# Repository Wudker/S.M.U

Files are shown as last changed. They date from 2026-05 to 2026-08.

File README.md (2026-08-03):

# S.M.U. – Custom RLC Component Meter

S.M.U. is a portable RLC meter based on the Raspberry Pi Pico, developed for testing coils and passive components during electronics prototyping. Resistance is measured using a voltage divider, capacitance through RC discharge timing to approximately 37% of the initial voltage, and inductance through LC resonance and frequency analysis. Custom measurement algorithms and automatic range switching process the signals, while an SSD1306 OLED presents the results. The device combines analog measurement circuits, embedded software, a custom PCB and Li-Ion power supply in a single enclosure.

## Technologies

`Raspberry Pi Pico` `C/C++` `ADC measurements` `RC time constant` `LC resonance` `LM339 comparator` `SSD1306 OLED` `Custom PCB` `Li-Ion battery`

## Usage and development status

Select resistance, capacitance or inductance mode, place the unpowered component in the measurement connector and start the measurement. Capacitors should always be fully discharged before being connected. The prototype has been built and tested; future improvements include increased accuracy, more reliable auto-ranging, improved stability and a redesigned analog front-end.

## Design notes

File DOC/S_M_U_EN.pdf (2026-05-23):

# S.M.U. Project

Final prototype documentation

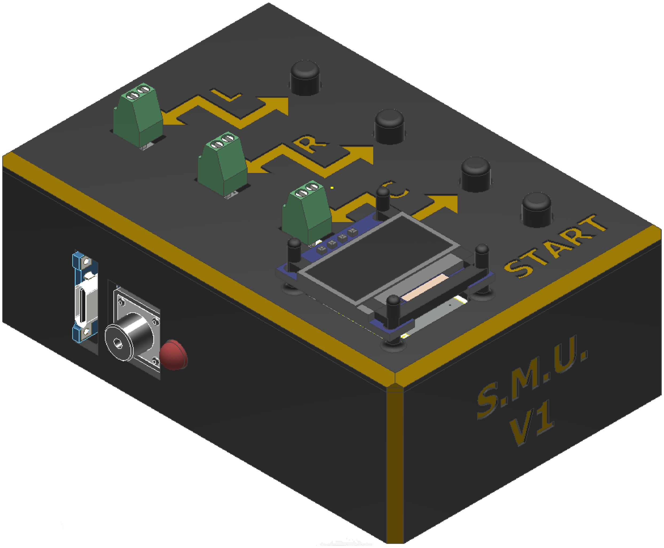
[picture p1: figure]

Author | Eng. Bartłomiej Dusza
Revision | Rev. A
Date | January 25, 2026
Version | 1.0

This document summarizes the prototype stage of the S.M.U. device and describes its design assumptions, construction and operation.

# Contents

1 Concept | 2
2 Application | 8
3 Direction of further development | 13

# Concept

## 1.1 Device idea and purpose

The aim of the project was to create a meter capable of measuring typical electronic components used in mechatronics. The version described in this document is a first prototype, built to check whether the selected measurement methods work in practice and to assess the possibility of developing a complete device. This part of the project focused mainly on the measurement section, while a ready-made microcontroller board was used for calculations and result interpretation. The Raspberry Pi Pico was selected for this project because it was inexpensive and allowed testing a different family of microcontrollers.

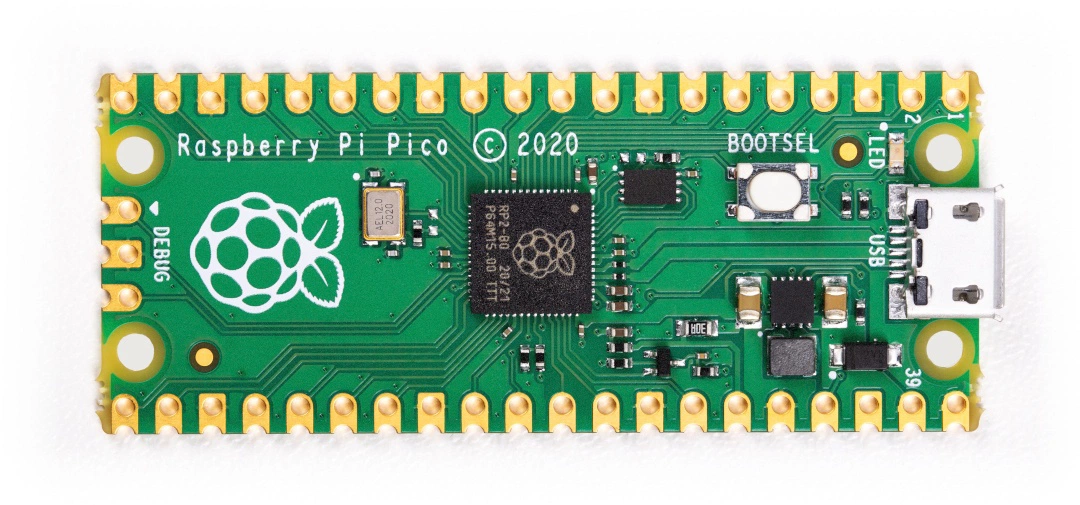
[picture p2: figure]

Figure 1.1: Selected microcontroller module.

## 1.2 Resistance measurement

Resistance measurement is based on a voltage divider and a reference resistor. The value of the measured resistor is calculated from the voltage measured by the microcontroller ADC.

The reference resistor values were selected to keep the ADC reading in a useful part of its input range for different measured resistances.

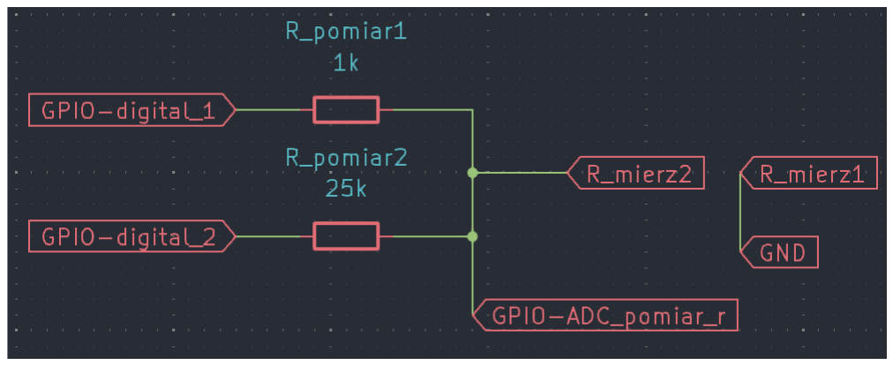
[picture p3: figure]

Figure 1.2: Resistance measurement circuit diagram.

## 1.3 Capacitance measurement

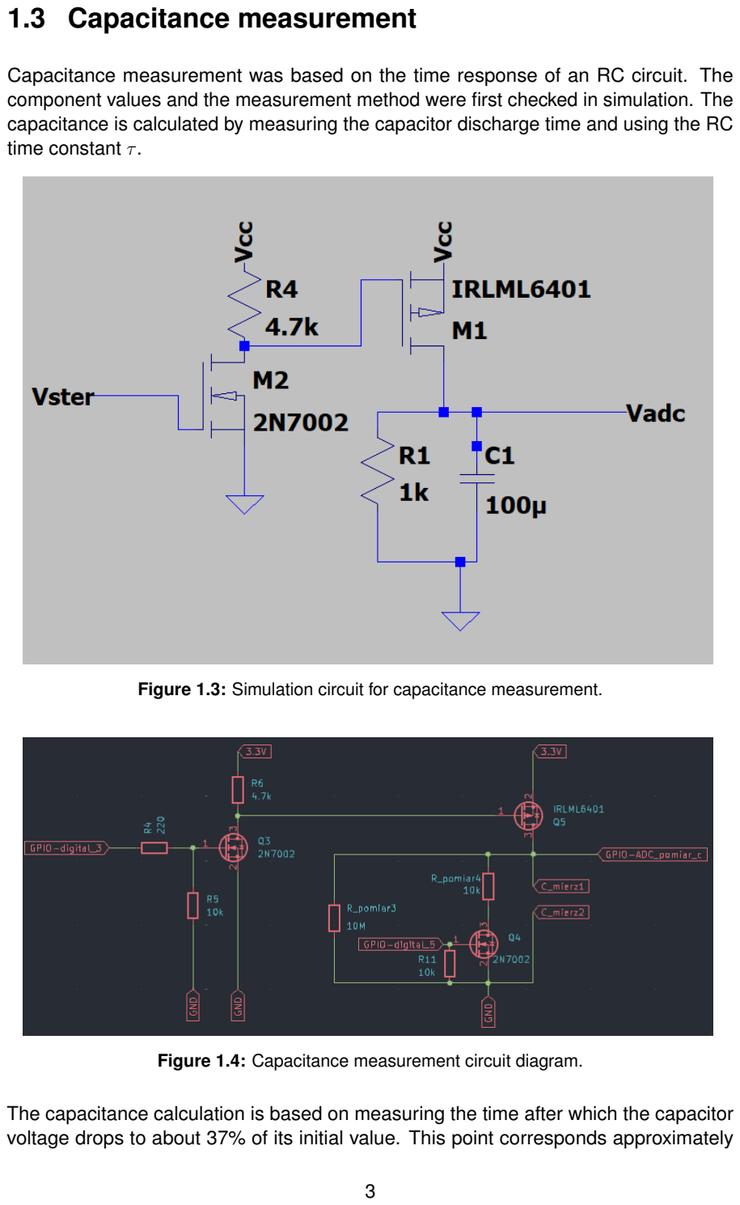
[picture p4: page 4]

Capacitance measurement was based on the time response of an RC circuit. The component values and the measurement method were first checked in simulation. The capacitance is calculated by measuring the capacitor discharge time and using the RC time constant τ .

Figure 1.3: Simulation circuit for capacitance measurement.

Figure 1.4: Capacitance measurement circuit diagram.

The capacitance calculation is based on measuring the time after which the capacitor voltage drops to about 37% of its initial value. This point corresponds approximately

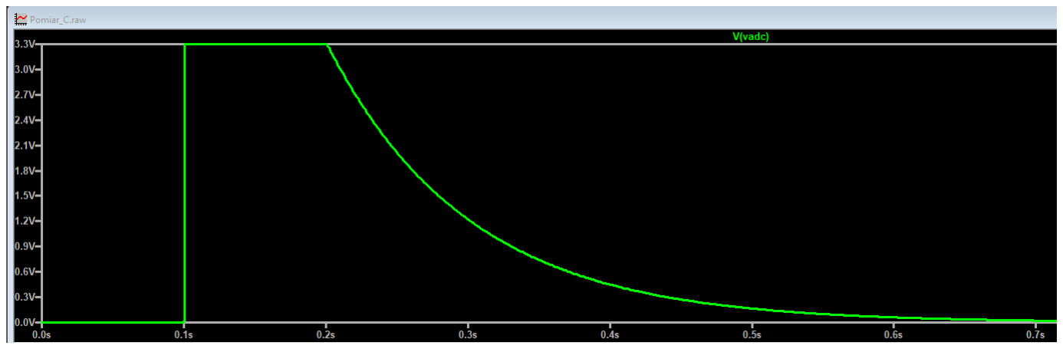
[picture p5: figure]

Figure 1.5: Simulation result of the measurement circuit.

to one time constant. Two measurement resistors were used to cover a wider range of capacitances. For large capacitances and a high resistance value, the measurement time could become too long. For small capacitances and a low resistance value, the discharge could be too fast for reliable measurement by the microcontroller. For this reason, an additional parallel resistor was added and switched by an N-MOSFET. This reduced the measurement resistance from 1 MΩ to about 10 kΩ when needed.

## 1.4 Inductance measurement

Inductance measurement was based on the resonant frequency of an LC circuit. Before building the practical circuit, simulations were performed to check the adopted measurement idea. The measured inductance is calculated from the resonant frequency of the LC circuit, using a known capacitance value.

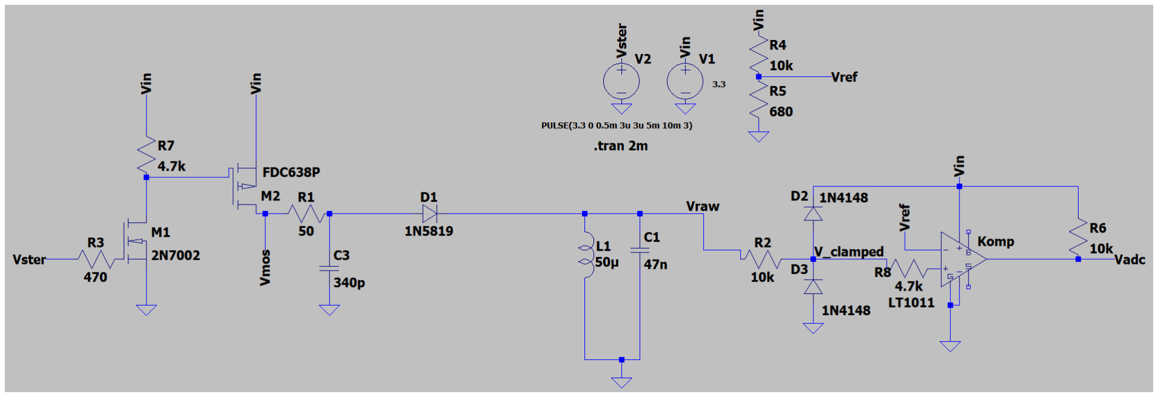
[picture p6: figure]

Figure 1.6: Simulation circuit for inductance measurement.

In the first version of the prototype, an amplifier was used between the resonant circuit and the comparator. After testing, it was removed because the circuit could work without it. The amplifier was originally intended to increase the amplitude of the signal from the resonant circuit. Schottky diodes were used as clamps to limit the negative part of the signal and allow the comparator to work correctly. The comparator converts the analog oscillating signal into a digital signal that is easier for the microcontroller to count.

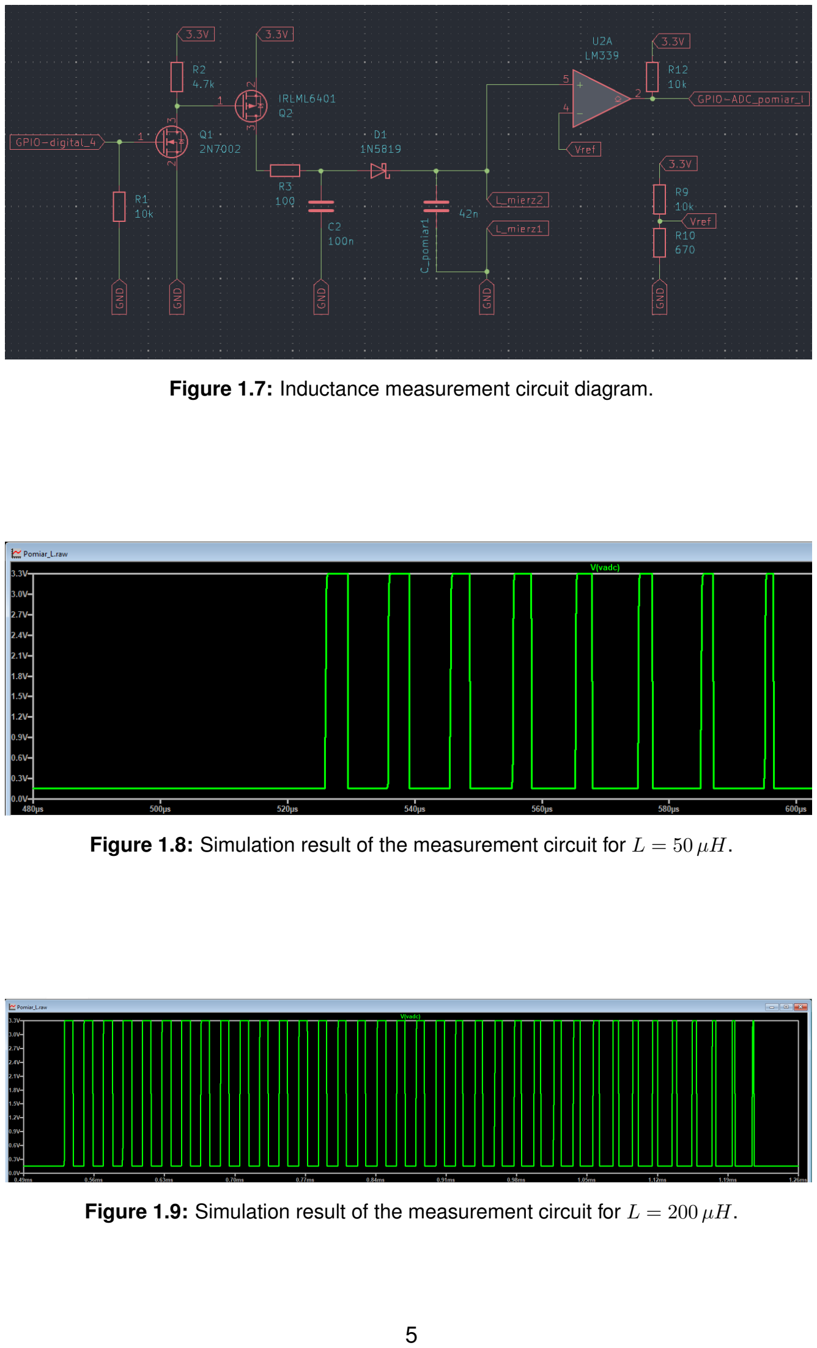
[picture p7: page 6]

Figure 1.7: Inductance measurement circuit diagram.

Figure 1.8: Simulation result of the measurement circuit for L = 50 µH.

Figure 1.9: Simulation result of the measurement circuit for L = 200 µH.

## 1.5 Power supply section

The project included USB power supply and the possibility of charging a battery cell. The power supply section was designed to make the device easy to use and allow further development.

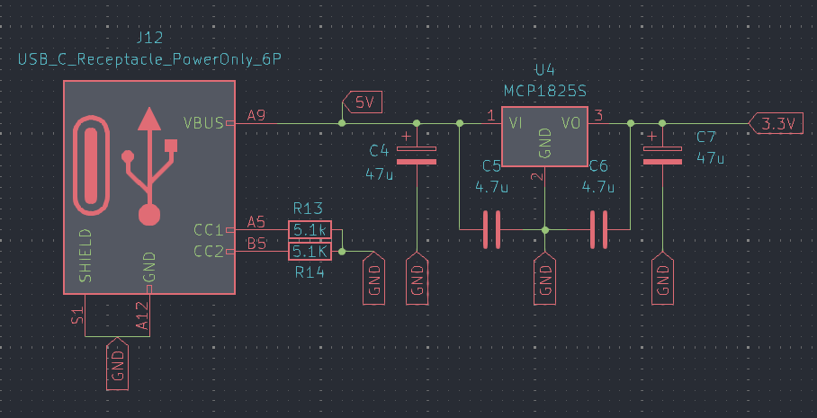
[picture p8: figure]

Figure 1.10: USB power supply handling circuit diagram.

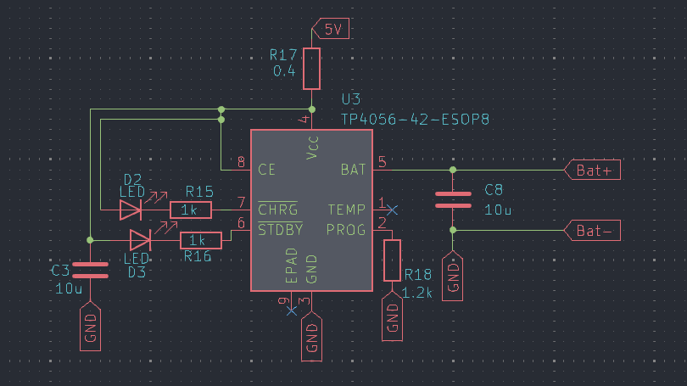
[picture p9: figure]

Figure 1.11: Battery cell charging circuit diagram.

Later, it was noticed that the TP4056 chip requires the “TEMP” pin to be connected to GND when this function is not used. More importantly, the chip is responsible only for the charging process and does not provide full battery protection. In this configuration, the circuit was not fully safe, because there was no protection system monitoring the battery cell. Such protection circuits usually use a pair of back-to-back N-MOSFETs to disconnect the cell from the system when an unsafe condition is detected. After analyzing this problem, the USB and TP4056 section was not assembled. Instead, a ready-made charging module with battery protection was used.

## 1.6 PCB

Based on the prepared schematic, a printed circuit board was designed. The top and bottom sides of the PCB are shown below.

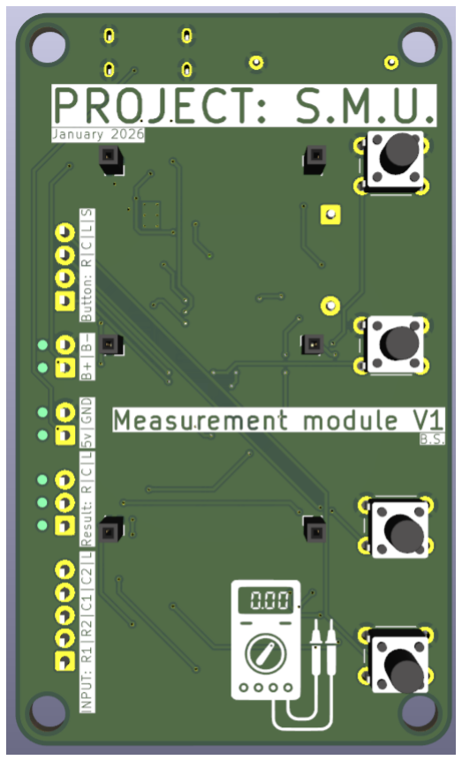
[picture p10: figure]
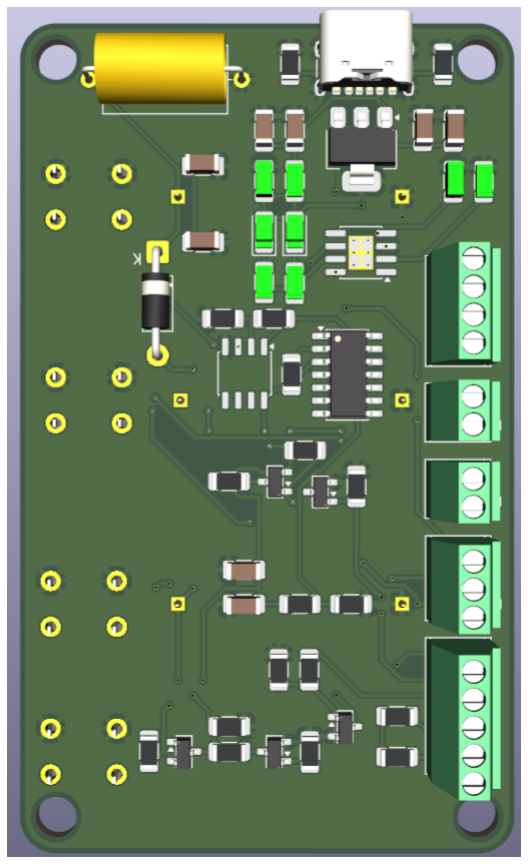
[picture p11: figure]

(a) PCB front side. | (b) PCB back side.

Figure 1.12: View of the designed PCB.

Compared with the original PCB design, the final assembled version does not include the TP4056 circuit or the amplifier, for the reasons described earlier. In addition, clamp diodes were added to ensure proper operation of the comparator. Another change was related to the measuring capacitor in the resonant path used for inductance measurement. A precision film capacitor with a different pin layout than the one used in the original design was installed.

# Application

## 2.1 Accuracy

To evaluate the operation of the device, a series of five measurements was performed for selected components. For resistance and capacitance, the results were compared with the average value obtained from a reference meter. For inductance, due to the lack of reference meter data, the results were compared with the nominal values of the tested coils.

### 2.1.1 Resistance

Results table

Table 2.1: Comparison of resistance measurement results

Element | Average value from reference meter | Average value from S.M.U. | Error relative to refer-ence
100 Ω | 97.64 Ω | 96.50 Ω | -1.17%
1 kΩ | 972.24 Ω | 956.23 Ω | -1.65%
47 kΩ | 46.962 kΩ | 44.032 kΩ | -6.24%
100 kΩ | 96.372 kΩ | 87.646 kΩ | -9.05%
1 MΩ | 1.0036 MΩ | 0.5204 MΩ | -48.15%

Description

Based on the measurements, the circuit correctly measures resistance in the lower and middle part of the tested range. For the 100 Ω and 1 kΩ resistors, the deviation from the reference value did not exceed 2%. As the measured resistance increased, the error also increased, which was visible for 47 kΩ and 100 kΩ. The largest deviation occurred for the 1 MΩ resistor, where the measured value was almost two times lower than the reference value.

Conclusions

The resistance measurement circuit can be considered suitable for low and medium resistance values. In the current prototype version, the biggest problems appear at high resistances, where ADC resolution, reference resistor tolerance and noise have a much stronger influence on the result. This section requires further improvement if the device is to measure values in the range of hundreds of kiloohms and megaohms reliably.

Theoretical and practical range

The theoretical resistance measurement range results directly from the voltage divider relation:

UADC = VCC

Rx
Rx + Rw
where Rx is the measured resistance and Rw is the reference resistor. In practice, the most useful ADC operating area is not at the very beginning or end of the scale, but rather in the middle part of the characteristic. With a simple assumption that, for more accurate calculation, it is convenient to keep the ADC input voltage in the range of about 10%–90% of full scale, the following relation is obtained:

0.1 ≤

Rx
Rx + Rw

≤ 0.9

which after transformation gives approximately:

0.11 Rw ≤ Rx ≤ 9 Rw

For an example reference resistor Rw = 10 kΩ, this gives a range of about:

1.1 kΩ ≤ Rx ≤ 90 kΩ

which is approximately from about 1 kΩ to 100 kΩ for more accurate calculation. With a wider but less favorable use of the ADC range, for example about 5%–95%, the approximate range would be from about 0.5 kΩ to about 190 kΩ. The actual results showed that in the current prototype version the useful range mainly covered values from about 100 Ω to about 100 kΩ, while for 1 MΩ the error was already too large to consider this point reliable.

### 2.1.2 Capacitance

Results table

Table 2.2: Comparison of capacitance measurement results

Element | Average value from reference meter | Average value from S.M.U. | Error relative to refer-ence
1000 µF | 1072.6 µF | 1036.0 µF | -3.41%
470 µF | 481.38 µF | 439.93 µF | -8.61%
100 µF | 124.24 µF | 102.14 µF | -17.79%
10 µF | 11.56 µF | 9.316 µF | -19.41%
100 nF | 146.03 nF | 32.08 nF | -78.03%

Description

For capacitance measurement, correct and repeatable results were obtained for larger capacitances, especially in the range of 470 µF–1000 µF. As the capacitance decreased, the measurement error increased. For 100 µF and 10 µF capacitors, the result was clearly lower than the reference value. For 100 nF, the measurement was incorrect. This shows that the method works well for larger time constants, but for small capacitances parasitic effects and timing limitations become dominant.

Conclusions

The capacitance measurement section works correctly for capacitors with larger values, while the lower range requires further optimization. The results suggest that in the current configuration the circuit is more useful for measuring electrolytic capacitors and larger capacitors than for precise measurement of small capacitances. In particular, for the nanofarad range, changing the measurement components or using another method should be considered.

Theoretical and practical range

For capacitance measurement, the starting point was the time constant relation:

τ = R C

where the measurement was based on determining the time required for the voltage to drop to about 37% of the initial value, which corresponds to one time constant τ . Two measuring resistors were used in the project: about 1 MΩ and about 10 kΩ, with the second value obtained by connecting a parallel branch. Therefore, the theoretical range can be estimated by assuming that a convenient measurement time for the microcontroller is roughly between 10 ms and 10 s.

For R = 1 MΩ:
C =

τ
R

Cmin ≈

10 ms
1 MΩ

= 10 nF

Cmax ≈

10 s
1 MΩ

= 10 µF

For R = 10 kΩ:

Cmin ≈

10 ms
10 kΩ

= 1 µF

Cmax ≈

10 s
10 kΩ

= 1000 µF

This gives a total theoretical range of about 10 nF to about 1000 µF, where the lower part of the range is mainly covered by the 1 MΩ resistor and the upper part by the resistor of about 10 kΩ. In practice, the obtained results showed that the current prototype version worked correctly mainly from about 10 µF to about 1000 µF. Although simple calculations suggest that lower values should also be possible, for small capacitances parasitic capacitances, component tolerances and timing limitations of the circuit became increasingly important. As a result, for 100 nF the error was already very large.

### 2.1.3 Inductance

Results table

Table 2.3: Comparison of inductance measurement results

Element | Nominal value | Average value from S.M.U. | Error relative to nomi-nal value
330 µH | 330 µH | 329.87 µH | -0.04%
220 µH | 220 µH | 170.09 µH | -22.69%
100 µH | 100 µH | 106.27 µH | +6.27%

Description

For inductance measurement, the results were mixed. For the 330 µH coil, the measured value was very close to the nominal value, which supports the measurement idea based on the resonant method. For 100 µH, the deviation was still acceptable. The biggest problem appeared for 220 µH, where the result was significantly lower than the nominal value. This may be caused by parasitic parameters of the tested coil, limited frequency counting stability or a faulty coil sample.

Conclusions

Inductance measurement can be considered promising, but in the current version it is not yet fully stable across the entire tested range. The very good result obtained for 330 µH shows that the circuit has potential, but the error spread for the other coils suggests the need for further calibration and better consideration of parasitic elements. In practice, this means that this section still requires improvement before it can be considered fully universal.

Theoretical and practical range

For inductance measurement, the relation for the resonant frequency of an LC circuit was used:
f =

1
2π

√
LC
after transformation:
L =

1
(2πf)
2C

Assuming a reference capacitor Cref = 42 nF, it is possible to estimate what inductance range corresponds to frequencies convenient for further counting and processing by the circuit. For an approximate frequency range from about 40 kHz to 110 kHz, the following values are obtained:

for f = 110 kHz:

L ≈

1
(2π · 110000)²
- 42 · 10⁻⁹

≈ 50 µH

for f = 40 kHz:

L ≈

1
(2π · 40000)²
- 42 · 10⁻⁹

≈ 377 µH

This gives a theoretical operating range of about:

50 µH ≤ L ≤ 380 µH

It is worth noting that for values close to the tested ones, frequencies consistent with the idea of this method are obtained: for 100 µH about 78 kHz, for 200 µH about 55 kHz, and for 330 µH about 43 kHz. This means that the adopted range from several dozen to several hundred µH was theoretically justified. In practice, values from 100 µH to 330 µH were tested, and the best agreement was obtained for 330 µH, while for 220 µH a clear error appeared. This shows that the method itself was correct, but the practical range of accurate measurement turned out to be narrower than the range resulting from a simple theoretical model.

Summary of the measurement section

The measurements confirmed that the adopted measurement methods can work in practice, but they also showed that the device accuracy strongly depends on the tested value range. The best results were obtained in the middle parts of the measurement ranges, where the values were close to the reference values and showed good repeatability. The largest deviations appeared at extreme values. This indicates the influence of method limitations, parasitic component parameters and the resolution of the measurement path. The prototype fulfilled its verification role and helped identify the areas that require further improvement.

# Direction of further development

After analyzing the results, it can be concluded that the measurement circuit concept is valid. However, the results also show that in the next version it is necessary to:

- carefully analyze the measurement ranges and add more measurement elements,
- remove the ready-made charging module,
- add protection circuits for the battery cell,
- replace the ready-made microcontroller module with a dedicated microcontroller circuit,
- analyze available microcontrollers and choose one with a suitable ADC, or use an external ADC,
- consider a better physical connector for the measured components,
- add protection against reverse connection of electrolytic capacitors.

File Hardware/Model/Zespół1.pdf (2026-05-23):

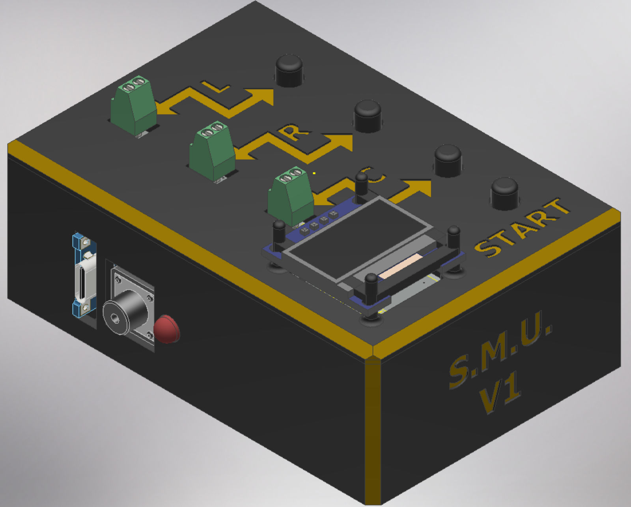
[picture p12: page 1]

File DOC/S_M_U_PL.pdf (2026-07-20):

Projekt S.M.U.

Dokumentacja koncowa prototypu ´


Autor | Inz. Bartłomiej Dusza ˙
Rewizja | Rev. A
Data | 25 stycznia 2026
Wersja | 1.0

Niniejszy dokument stanowi podsumowanie etapu projektu urz ˛adzenia oraz opis jego załoze˙ n,´ budowy i działania.

# Spis tresci ´

1 Pomysł | 2
1.3 Pomiar pojemnosci | ´ | 3
2 Zastosowanie | 8
2.1 Dokładnos´c | ´ | 8
2.1.2 Pojemnos´c | ´ | 9
3 Kierunek rozwoju | 13

# Pomysł

## 1.1 Idea i cel urz ˛adzenia

Celem projektu było stworzenie miernika umozliwiaj ˛acego pomiar warto ˙ | sci typowych ´
elementów elektronicznych wykorzystywanych w zakresie mechatroniki. Opisana w tym dokumencie wersja stanowi pierwszy krok maj ˛acy na celu sprawdzenie poprawnosci ´
idei pomiarów oraz ocen˛e mozliwo ˙ | sci wykonania kompletnego układu. Cz˛e ´ | s´c projektu ´
skupiała si˛e głównie na sekcji pomiarowej, a do obliczen i interpretacji wyników wyko- ´ rzystano gotow ˛a płytk˛e z mikrokontrolerem. Dla tego projektu wybrano Raspberry Pi Pico; decyzj˛e t˛e podj˛eto ze wzgl˛edu na ch˛ec sprawdzenia pracy z t ˛a rodzin ˛a układów ´ oraz korzystn ˛a cen˛e.

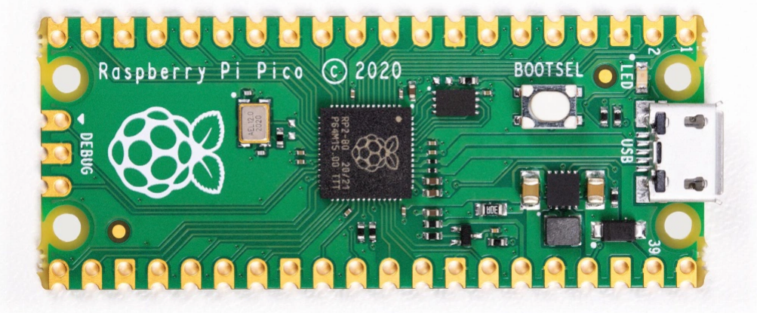
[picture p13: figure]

Rysunek 1.1: Wybrany moduł mikrokontrolera.

## 1.2 Pomiar rezystancji

Zamysł pomiaru rezystancji opiera si˛e na wykorzystaniu dzielnika napi˛ecia oraz dokładnego rezystora wzorcowego. Wartos´c mierzonego rezystora obliczana jest na podstawie ´ spadków napi˛ecia w obwodzie.

W celu dobrania wartosci rezystorów wzorcowych kierowano si˛e bilansem pomi˛edzy ´ skrajnym zakresem wartosci odczytywanych przez przetwornik ADC mikrokontrolera. ´

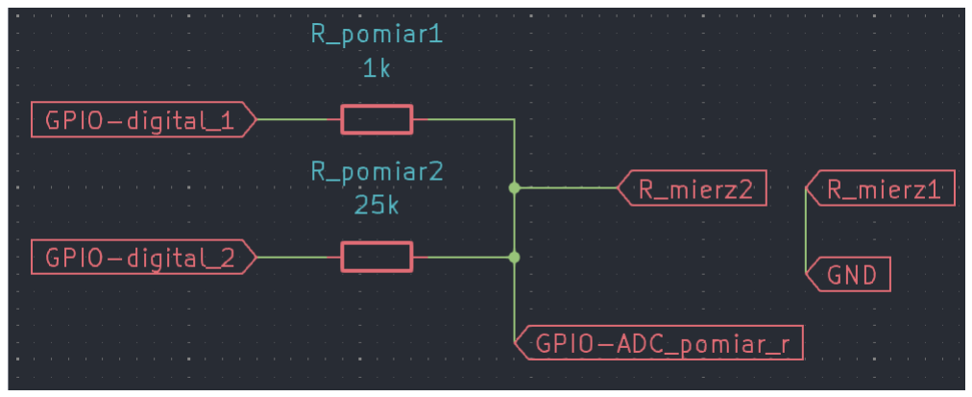
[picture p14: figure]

Rysunek 1.2: Schemat układu pomiaru rezystancji.

## 1.3 Pomiar pojemnosci ´

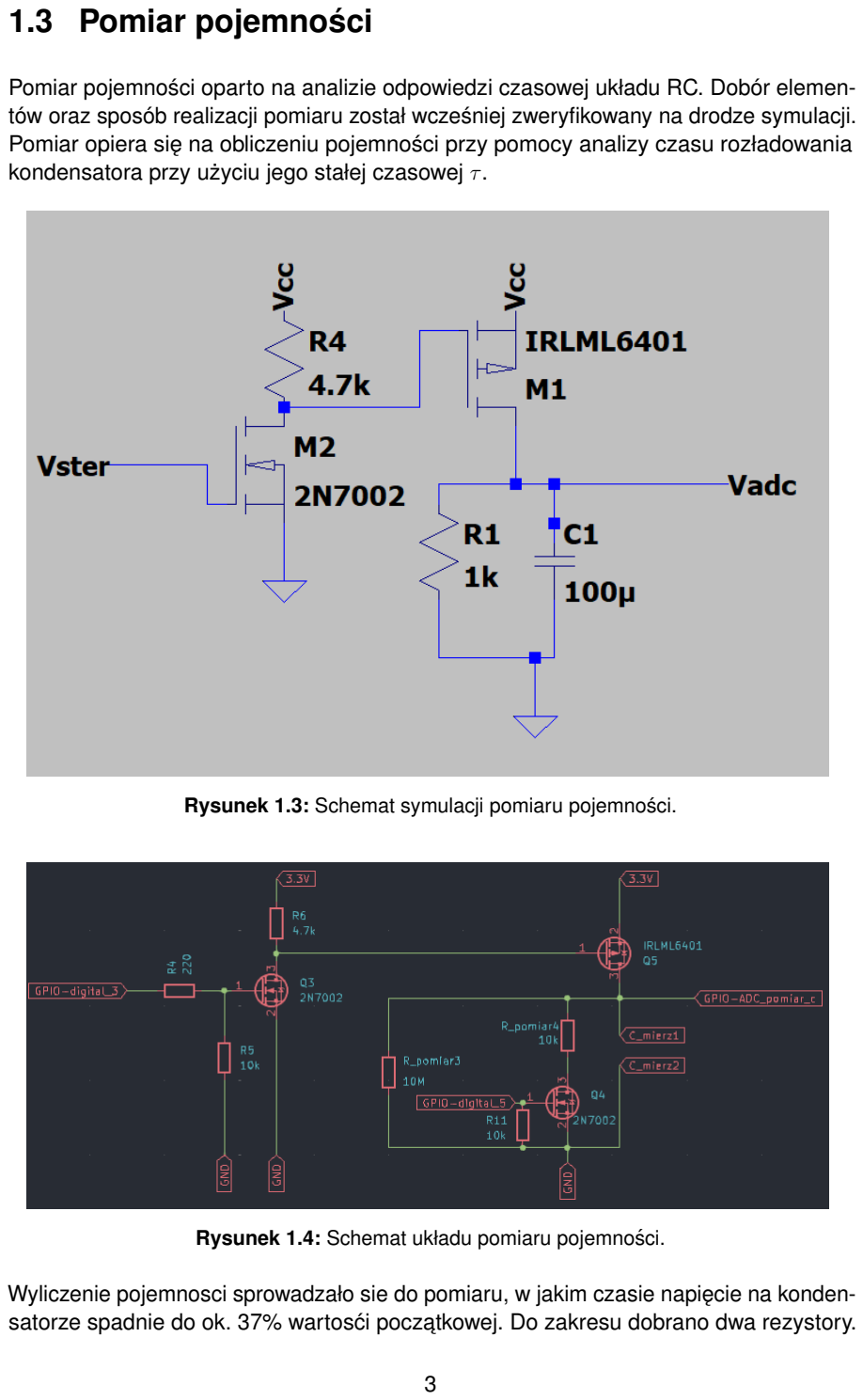
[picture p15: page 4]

Pomiar pojemnosci oparto na analizie odpowiedzi czasowej układu RC. Dobór elemen- ´ tów oraz sposób realizacji pomiaru został wczesniej zweryfikowany na drodze symulacji. ´ Pomiar opiera si˛e na obliczeniu pojemnosci przy pomocy analizy czasu rozładowania ´
kondensatora przy uzyciu jego stałej czasowej ˙ | τ .

Rysunek 1.3: Schemat symulacji pomiaru pojemnosci. ´

Rysunek 1.4: Schemat układu pomiaru pojemnosci. ´

Wyliczenie pojemnosci sprowadzało sie do pomiaru, w jakim czasie napi˛ecie na kondensatorze spadnie do ok. 37% wartosci pocz ˛atkowej. Do zakresu dobrano dwa rezystory. ´


Rysunek 1.5: Wynik symulacji układu pomiarowego.

Wybór dwóch wpływa na kultur˛e pracy, poniewaz dla du ˙ | zych pojemnosci oraz du ˙ | zych ˙
wartosci R pomiarowego czas pomiaru mogłby wynosi ´ | c minuty, natomiast przy małym ´
R oraz małym C mierzonym czas pomiaru mógłby byc zbyt szybki dla mikrokontrolera, ´
aby poprawnie obliczyc warto ´ | sc. Dlatego dodano rezystor równoległy podpinany pod ´
ukł ˛ad poprzez N-Mosfeta, zmniejszaj ˛acy R pomiarowe z 1M do ok 10k.

## 1.4 Pomiar induktancji

Pomiar induktancji oparto na analizie zachowania obwodu LC oraz cz˛estotliwosci od- ´ powiedzi układu. Przed implementacj ˛a praktyczn ˛a wykonano symulacje umozliwiaj ˛ace ˙
ocen˛e poprawnosci przyj˛etych zało ´ | ze˙ n. Cała idea pomiaru induktancji opiera sie na ´
analizie czestotliwosci rezonansowej układu LC przy znanej warto ´ | sci pojemnosci. ´

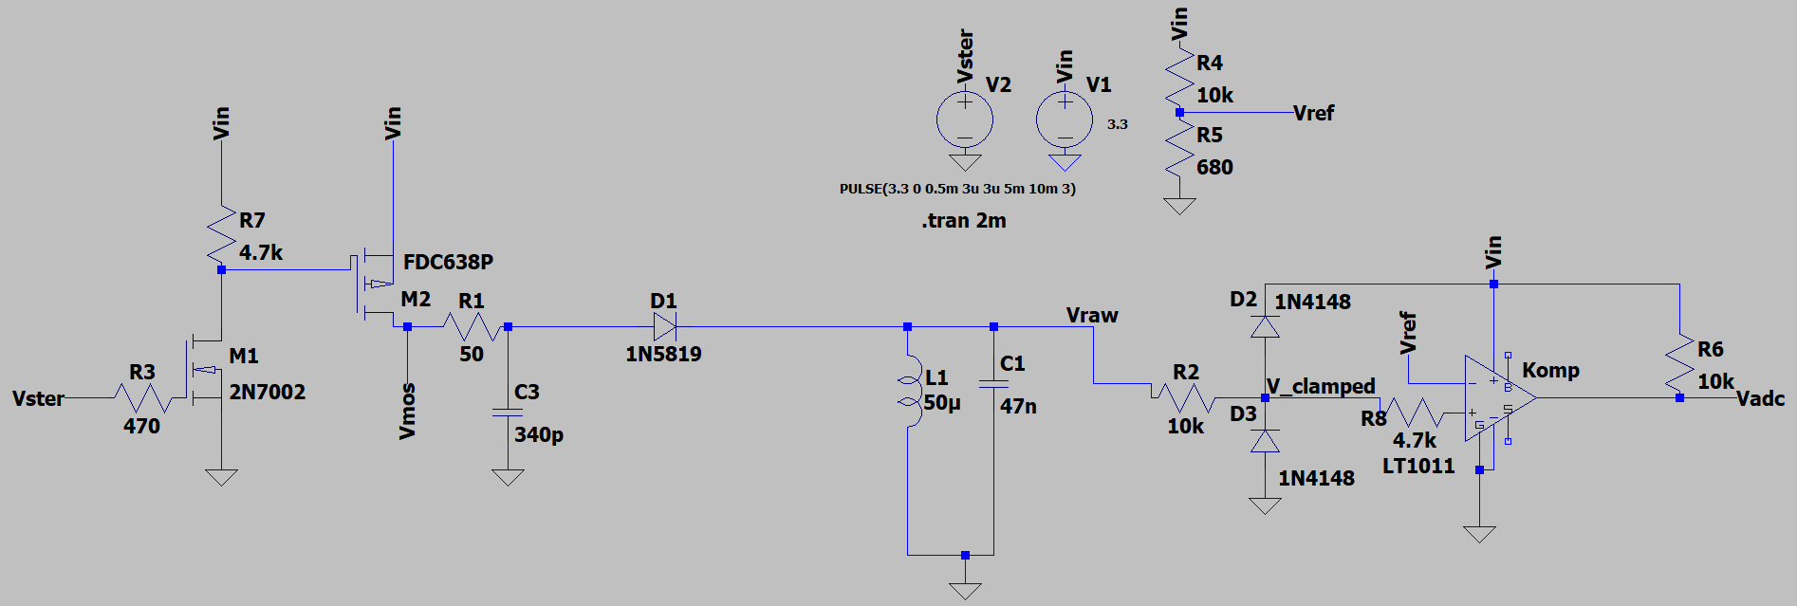
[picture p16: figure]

Rysunek 1.6: Schemat symulacji pomiaru induktancji.

W pocz ˛atkowej fazie prototypowania wykorzystano wzmacniacz miedzy układem rezonansowym a komparatorem, jednak po testach zdecydowano sie na jego usuni˛ecie. Celem wzmacniacza miało byc zwi˛ekszenie amplitudy sygnału wychodz ˛acego z re- ´ zonansu. Wykorzystanie diod Shottky’ego jako "clamp’ów"pozwoliło zminimalizowac´
doln ˛a cz˛es´c sygnału, co umo ´ | zliwiło poprawn ˛a prac˛e komparatora. Sygnał przechodzi ˙
przez komperator w celu ułatwienia pracy oraz zwi˛ekszania dokładnosci wyników na ´ mikrokontolerze.

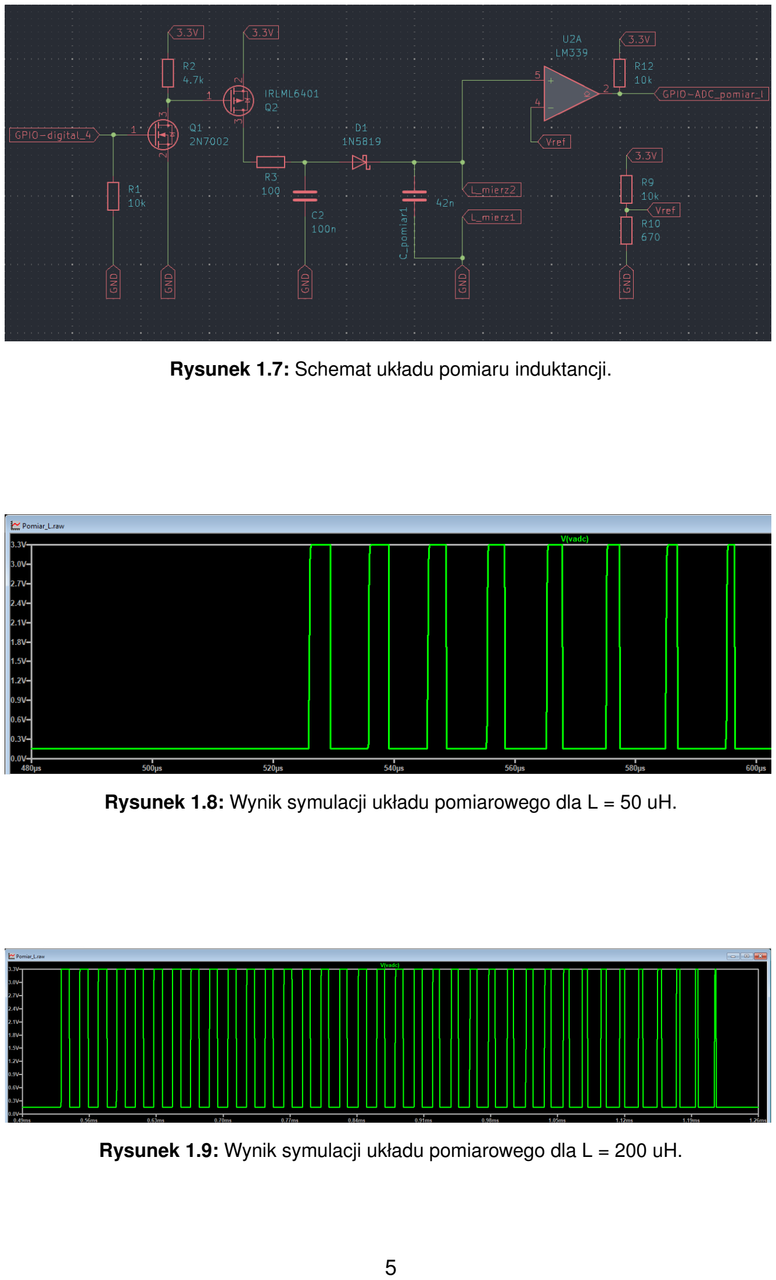
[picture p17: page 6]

Rysunek 1.7: Schemat układu pomiaru induktancji.

Rysunek 1.8: Wynik symulacji układu pomiarowego dla L = 50 uH.

Rysunek 1.9: Wynik symulacji układu pomiarowego dla L = 200 uH.

## 1.5 Sekcja zasilania

W projekcie przewidziano zarówno zasilanie z portu USB, jak i mozliwo ˙ s´c ładowa- ´ nia ogniwa. Układ zasilania zaprojektowano tak, aby mozliwa była wygodna obsługa ˙ urz ˛adzenia oraz jego pó´zniejsza rozbudowa.

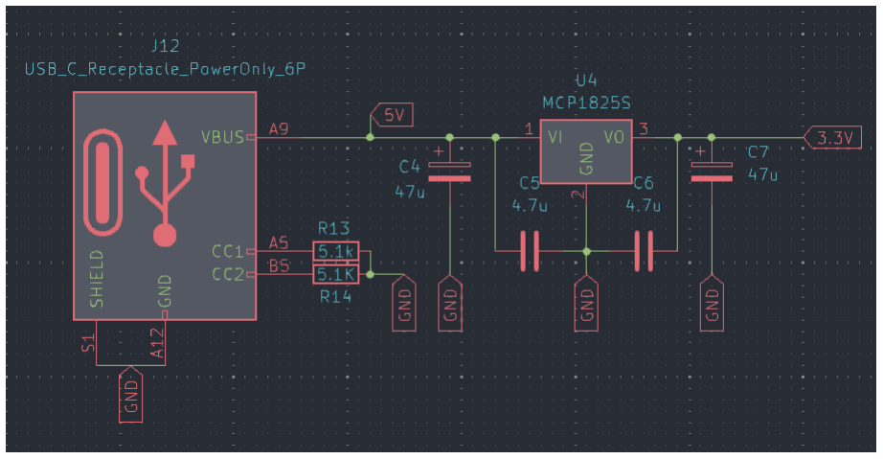
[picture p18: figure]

Rysunek 1.10: Schemat układu obsługi zasilania USB.


Rysunek 1.11: Schemat układu ładowania ogniwa.

W pó´zniejszym czasie spostrzezono, ˙ | ze u ˙ | zyty w projekcie układ wymaga podpi˛ecia pinu ˙
"TEMP"do GND przy nieuzywaniu go, oraz co wa ˙ | zniejsze, ˙ | ze układ ten odpowiedzialny ˙
jest wył ˛acznie za profil ładowania ogniwa. Układ ten zatem przy takim podł ˛aczeniu nie był w pełni bezpieczny, poniewaz brakowało układu odpowiedzialnego za monitoring ˙ pracy ogniwa. Układy takie najcz˛esciej wykorzystuj ˛a par˛e N-Mosfet’ów w konfiguracji ´ Back-to-back w celu odci˛ecia ogniwa od systemu przy wykryciu nieprawidłowej pracy. Po przeanalizowaniu zagroze˙ n wynikaj ˛acych z nieprawidłowego podł ˛aczenia zdecy- ´ dowano sie pomin ˛ac sekcje USB i TP4056 na rzecz gotowego modułu zawieraj ˛acego wymienione wczesniej zabezpieczenie. ´

## 1.6 PCB

Na podstawie opracowanego schematu przygotowano projekt płytki drukowanej. Ponizej ˙ przedstawiono widok warstwy górnej oraz dolnej.


(a) Przód PCB. | (b) Tył PCB.

Rysunek 1.12: Widok zaprojektowanej płytki PCB.

Wzgl˛edem projektu finalna wersja PCB nie posiada układów TP4056 oraz wzmacniacza z wymienionych wczesniej powodów. Ponadto przytulono diody clampowe w celu po- ´ prawnego działania komparatora. Finalna zmiana dotyczy kondensatora pomiarowego w torze rezonansowym pomiaru indukcyjnosci, zastosowano rezystor precyzyjny foliowy ´ o innym rozkładzie pinów niz u˙ zyty w projekcie. ˙

# Zastosowanie

## 2.1 Dokładnos´c´

W celu oceny poprawnosci działania urz ˛adzenia wykonano serie po 5 pomiarów dla ´
wybranych elementów. Dla rezystancji oraz pojemnosci wyniki porównano ze ´ | sredni ˛a ´
wartosci ˛a otrzyman ˛a z miernika referencyjnego. W przypadku induktancji, z uwagi na ´ brak danych z miernika referencyjnego, wyniki odniesiono do wartosci znamionowych ´ badanych cewek.

### 2.1.1 Rezystancja

Tabela wyników

Tabela 2.1: Porównanie wyników pomiaru rezystancji

Element | Sr. warto ´ s´c z miernika ´ referencyjnego | Sr. warto ´ s´c z S.M.U. ´ | Bł ˛ad wzgl˛edem odnie-sienia
100 Ω | 97.64 Ω | 96.50 Ω | -1.17%
1 kΩ | 972.24 Ω | 956.23 Ω | -1.65%
47 kΩ | 46.962 kΩ | 44.032 kΩ | -6.24%
100 kΩ | 96.372 kΩ | 87.646 kΩ | -9.05%
1 MΩ | 1.0036 MΩ | 0.5204 MΩ | -48.15%

Opis

Na podstawie przeprowadzonych pomiarów mozna stwierdzic,´ ze układ poprawnie ˙
realizuje pomiar rezystancji w dolnej i srodkowej cz˛e ´ | sci badanego zakresu. Dla ele- ´
mentów 100 Ω oraz 1 kΩ uzyskano niewielkie odchylenia od wartosci referencyjnych, ´ nieprzekraczaj ˛ace 2%. Wraz ze wzrostem mierzonej rezystancji bł ˛ad zaczynał rosn ˛ac,´ co było widoczne dla 47 kΩ oraz 100 kΩ. Najwi˛eksze odchylenie wyst ˛apiło dla rezystora 1 MΩ, dla którego wynik był zanizony niemal o połow˛e. ˙

Wnioski

Układ pomiaru rezystancji mozna uzna ˙ | c za poprawny dla małych i ´ | srednich warto ´ | sci ´
rezystancji. W obecnej wersji prototypu najwi˛eksze problemy pojawiaj ˛a si˛e przy bardzo
duzych rezystancjach, gdzie wpływ rozdzielczo ˙ | sci ADC, niedokładno ´ | sci rezystorów ´
wzorcowych oraz zakłócen ma ju ´ | z wyra´znie wi˛eksze znaczenie. Oznacza to, ˙ | ze sekcja ˙
ta wymaga dalszego dopracowania, jezeli układ ma wiarygodnie mierzy ˙ | c warto ´ | sci rz˛edu ´
setek kiloohmów i megaohmów.

Zakres teoretyczny i faktyczny

Teoretyczny zakres pomiaru rezystancji wynika bezposrednio z zale ´ | zno ˙ | sci dzielnika ´
napi˛ecia:

UADC = VCC

Rx
Rx + Rw
gdzie Rx jest rezystancj ˛a mierzon ˛a, a Rw rezystorem wzorcowym. W praktyce najbardziej uzyteczny obszar pracy ADC nie przypada przy samym 0% i 100% zakresu, lecz ˙
raczej w srodkowej cz˛e ´ | sci charakterystyki. Przy prostym zało ´ | zeniu, ˙ | ze do dokładniej- ˙
szego obliczenia wygodnie jest utrzymac napi˛ecie wej ´ | sciowe ADC w zakresie około ´
10%–90% pełnej skali, otrzymuje si˛e zalezno ˙ | s´c:´

0.1 ≤

Rx
Rx + Rw

≤ 0.9

co po przekształceniu daje w przyblizeniu: ˙

0.11 Rw ≤ Rx ≤ 9 Rw

Dla przykładowego rezystora wzorcowego Rw = 10 kΩ daje to zakres około:

1.1 kΩ ≤ Rx ≤ 90 kΩ

czyli w przyblizeniu od około ˙ | 1 kΩ do 100 kΩ dla dokładniejszego obliczenia. Przy szer-
szym, ale mniej korzystnym wykorzystaniu zakresu ADC, np. około 5%–95%, otrzymano
by juz orientacyjnie od około ˙ | 0.5 kΩ do około 190 kΩ. Faktycznie uzyskane wyniki poka-
zały, ze w obecnej wersji prototypu zakres u ˙ | zyteczny obejmował głównie warto ˙ | sci od ´
około 100 Ω do około 100 kΩ, natomiast dla 1 MΩ bł ˛ad był juz zbyt du ˙ | zy, aby uzna ˙ | c ten ´
punkt za wiarygodny.

### 2.1.2 Pojemnos´c´

Tabela wyników

Tabela 2.2: Porównanie wyników pomiaru pojemnosci ´

Element | Sr. warto ´ s´c z miernika ´ referencyjnego | Sr. warto ´ s´c z S.M.U. ´ | Bł ˛ad wzgl˛edem odnie-sienia
1000 µF | 1072.6 µF | 1036.0 µF | -3.41%
470 µF | 481.38 µF | 439.93 µF | -8.61%
100 µF | 124.24 µF | 102.14 µF | -17.79%
10 µF | 11.56 µF | 9.316 µF | -19.41%
100 nF | 146.03 nF | 32.08 nF | -78.03%

Opis

Dla pomiaru pojemnosci uzyskano poprawne i powtarzalne wyniki dla wi˛ekszych pojem- ´
nosci, szczególnie w zakresie 470 ´ | µF–1000 µF. Wraz ze zmniejszaniem pojemnosci ´
bł ˛ad pomiaru stopniowo wzrastał. Dla kondensatorów 100 µF oraz 10 µF wynik był
juz wyra´znie zani ˙ | zony wzgl˛edem warto ˙ | sci referencyjnej, natomiast dla 100 nF pomiar ´
okazał si˛e niepoprawny. Wskazuje to, ze zastosowana metoda dobrze sprawdza si˛e ˙ dla wi˛ekszych stałych czasowych, lecz przy małych pojemnosciach wpływ bł˛edów ´
pasozytniczych i ogranicze ˙ | n czasowych układu staje si˛e dominuj ˛acy. ´

Wnioski

Sekcja pomiaru pojemnosci działa poprawnie dla kondensatorów o wi˛ekszych warto- ´
sciach, natomiast w dolnym zakresie wymaga dalszej optymalizacji. Wyniki sugeruj ˛a, ´ | ze˙
w obecnej konfiguracji układ jest bardziej przydatny do pomiarów elektrolitów i wi˛ekszych
kondensatorów niz do precyzyjnego pomiaru małych pojemno ˙ | sci. W szczególno ´ | sci dla ´
zakresu nanofaradów nalezałoby rozwa ˙ | zy˙ c zmian˛e elementów pomiarowych lub zasto- ´
sowanie innej metody.

Zakres teoretyczny i faktyczny

Dla pomiaru pojemnosci punktem wyj ´ | scia była zale ´ | zno ˙ | s´c stałej czasowej: ´

τ = R C

przy czym pomiar opierał si˛e na wyznaczeniu czasu spadku napi˛ecia do około 37%
wartosci pocz ˛atkowej, czyli do jednej stałej czasowej ´ | | | τ . W projekcie wykorzystano dwa
rezystory pomiarowe: około 1 MΩ oraz około 10 kΩ, przy czym drugi uzyskiwano przez
doł ˛aczenie równoległej gał˛ezi. Mozna wi˛ec oszacowa ˙ | c zakres teoretyczny, przyjmuj ˛ac ´
orientacyjnie, ze wygodny czas pomiaru dla mikrokontrolera mie ˙ | sci si˛e mniej wi˛ecej od ´
10 ms do 10 s.

Dla R = 1 MΩ:
C =

τ
R
| Cmin ≈

10 ms
1 MΩ
| | = 10 nF

Cmax ≈

10 s
1 MΩ

= 10 µF

Dla R = 10 kΩ:

Cmin ≈

10 ms
10 kΩ

= 1 µF

Cmax ≈

10 s
10 kΩ

= 1000 µF

Daje to wi˛ec teoretyczny zakres ł ˛aczny rz˛edu od około 10 nF do około 1000 µF, przy
czym dolna cz˛es´c zakresu przypada głównie dla rezystora ´ | 1 MΩ, a górna dla rezystora
około 10 kΩ. W praktyce otrzymane wyniki pokazały, ze obecna wersja prototypu działała ˙

poprawnie głównie od około 10 µF do około 1000 µF. Mimo ze z prostych oblicze ˙ | n´
wynika mozliwo ˙ | s´c zej ´ | scia ni ´ | zej, przy małych pojemno ˙ | sciach coraz wi˛eksze znaczenie ´
miały pojemnosci paso ´ | zytnicze, rozrzut elementów oraz ograniczenia czasowe samego ˙
układu, przez co juz dla ˙ | 100 nF bł ˛ad był bardzo duzy. ˙

### 2.1.3 Induktancja

Tabela wyników

Tabela 2.3: Porównanie wyników pomiaru indukcyjnosci ´

Element | Wartos´c nominalna ´ | Sr. warto ´ s´c z S.M.U. ´ | Bł ˛ad wzgl˛edem warto-sci nominalnej ´
330 µH | 330 µH | 329.87 µH | -0.04%
220 µH | 220 µH | 170.09 µH | -22.69%
100 µH | 100 µH | 106.27 µH | +6.27%

Opis

W przypadku pomiaru induktancji uzyskano zróznicowane wyniki. Dla cewki 330 ˙ | µH
pomiar był bardzo bliski wartosci nominalnej, co potwierdza poprawno ´ | s´c samej idei ´
pomiaru metod ˛a rezonansow ˛a. Dla 100 µH odchylenie nadal pozostawało na akceptowalnym poziomie. Najwi˛ekszy problem pojawił si˛e dla 220 µH, gdzie wynik był znacz ˛aco
zanizony. Mo ˙ | ze to wskazywa ˙ | c na wpływ parametrów paso ´ | zytniczych badanej cewki, ˙
ograniczon ˛a stabilnos´c zliczania cz˛estotliwo ´ | sci lub wadliwy egzemplarz samej cewki. ´

Wnioski

Pomiar induktancji mozna uzna ˙ | c za obiecuj ˛acy, jednak w obecnej wersji nie jest jeszcze ´
w pełni stabilny w całym badanym zakresie. Otrzymany bardzo dobry wynik dla 330 µH pokazuje, ze układ ma potencjał, ale rozrzut bł˛edów dla pozostałych cewek sugeruje ˙ potrzeb˛e dalszej kalibracji oraz lepszego uwzgl˛ednienia elementów pasozytniczych. W ˙ praktyce oznacza to, ze sekcja ta wymaga jeszcze dopracowania przed uznaniem jej za ˙ w pełni uniwersaln ˛a.

Zakres teoretyczny i faktyczny

Dla pomiaru indukcyjnosci wykorzystano zale ´ | zno ˙ | s´c na cz˛estotliwo ´ | s´c rezonansow ˛a ´
układu LC:
f =

1
2π

√
LC
po przekształceniu:

L =

1
(2πf)
2C

Przy załozeniu kondensatora wzorcowego ˙ | Cref = 42 nF mozna oszacowa ˙ | c, jaki za- ´
kres indukcyjnosci odpowiada cz˛estotliwo ´ | sciom wygodnym do dalszego zliczania i ´
obróbki przez układ. Dla orientacyjnego zakresu cz˛estotliwosci około ´ | 40 kHz do 110 kHz
otrzymuje si˛e:

dla f = 110 kHz:

L ≈

1
(2π · 110000)²
- 42 · 10⁻⁹

≈ 50 µH

dla f = 40 kHz:

L ≈

1
(2π · 40000)²
- 42 · 10⁻⁹

≈ 377 µH

Daje to teoretyczny zakres roboczy rz˛edu:

50 µH ≤ L ≤ 380 µH

Warto zauwazy˙ c,´ ze dla warto ˙ | sci zbli ´ | zonych do testowanych otrzymuje si˛e cz˛estotliwo ˙ | sci ´
zgodne z intuicj ˛a tej metody: dla 100 µH około 78 kHz, dla 200 µH około 55 kHz, a dla
330 µH około 43 kHz. Oznacza to, ze przyj˛ety zakres kilkudziesi˛eciu do kilkuset ˙ | µH był
uzasadniony teoretycznie. Faktycznie przetestowano wartosci od ´ | 100 µH do 330 µH i
najlepsz ˛a zgodnos´c uzyskano dla ´ | | 330 µH, natomiast dla 220 µH pojawił si˛e juz wyra´zny ˙
bł ˛ad. Pokazuje to, ze sama metoda była poprawna, lecz praktyczny zakres dokładnego ˙ pomiaru okazał si˛e w˛ezszy ni ˙ z zakres wynikaj ˛acy z prostego modelu teoretycznego. ˙

Podsumowanie sekcji pomiarowej

Przeprowadzone pomiary potwierdziły poprawnos´c przyj˛etych zało ´ | ze˙ n projektowych, ´
jednak wykazały równiez,˙ ze dokładno ˙ | s´c urz ˛adzenia silnie zale ´ | zy od badanego zakresu ˙
wartosci. Najlepsze rezultaty uzyskano dla ´ | srednich zakresów pomiarowych, gdzie wy- ´
niki były zblizone do warto ˙ | sci referencyjnych oraz cechowały si˛e dobr ˛a powtarzalno ´ | sci ˛a. ´
Najwi˛eksze odchylenia pojawiały si˛e przy wartosciach skrajnych, co wskazuje na wpływ ´
ograniczen zastosowanej metody, parametrów elementów paso ´ | zytniczych oraz rozdziel- ˙
czosci toru pomiarowego. Oznacza to, ´ | ze prototyp spełnił swoj ˛a rol˛e weryfikacyjn ˛a i ˙
pozwolił wskazac obszary wymagaj ˛ace dalszego dopracowania. ´

# Kierunek rozwoju

Do przeanalizowania wyników uwaza si˛e, ˙ | ze idea układów pomiarowych ma sens. ˙
Wyniki jednak wskazuj ˛a wyra´znie, ze w nast˛epnej wersji nale ˙ | zy: ˙
- Przeanalizowanie dokładne zakresów i dodanie wi˛ecej elementów pomiarowych
- Zrezygnowanie z gotowego modułu ładowania
- Dodanie układów ochronnych dla ogniwa
- Zrezygnowano z gotowego modułu mikrokontrolera
- Przeanalizowanie dost˛epnych mikrokontrolerów i wybranie tego z odpowiednim ADC lub zdecydowanie si˛e na zewn˛etrzny ADC
- Rozwazenie lepszej metody fizycznego poł ˛aczenia elementów mierzonych ˙
- Dodanie zabezpieczenia dla kondensatorów elektrolitycznych przed odwrotnym podł ˛aczeniem.

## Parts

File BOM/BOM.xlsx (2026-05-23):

Nazwa | Wartośc | Footprint | Link | Link
C1 | 340p | Capacitor_SMD:C_1206_3216Metric | TAK | https://www.tme.eu/pl/details/c1206c331j5gac/kondensatory-mlcc-smd/kemet/c1206c331j5gactu/
> C2, C9, C10 | 100n | Capacitor_SMD:C_1206_3216Metric | TAK | https://www.tme.eu/pl/details/cl31b104kbcnnnc/kondensatory-mlcc-smd/samsung/
> C3, C8 | 10u | Capacitor_SMD:C_1206_3216Metric | TAK | https://www.tme.eu/pl/details/cl31b106kbhnnne/kondensatory-mlcc-smd/samsung/
> C4, C7 | 47u | Capacitor_SMD:C_1206_3216Metric | TAK | https://www.tme.eu/pl/details/cl31a476mphnnne/kondensatory-mlcc-smd/samsung/
> C5, C6 | 4.7u | Capacitor_SMD:C_1206_3216Metric | TAK | https://www.tme.eu/pl/details/cl31b475kbhnnne/kondensatory-mlcc-smd/samsung/
C_pomiar1 | 42n | Capacitor_THT:C_Axial_L12.0mm_D6.5mm_P15.00mm_Horizontal | TAK | https://www.tme.eu/pl/details/mkp2-47n_250-r-5/kondensatory-foliowe-tht/wima/mkp2f024701c00jssd/
D1 | 1N5819 | Diode_THT:D_DO-41_SOD81_P10.16mm_Horizontal | TAK | https://www.tme.eu/pl/details/1n5819-dio/diody-schottky-tht/diotec-semiconductor/1n5819/
> D2, D3 | LED | LED_SMD:LED_1206_3216Metric | TAK | https://www.tme.eu/pl/details/of-smd3216r/diody-led-smd-kolorowe/optoflash/
J1 | Bateria | TerminalBlock_Phoenix:TerminalBlock_Phoenix_MPT-0,5-2-2.54_1x02_P2.54mm_Horizontal | TAK | https://botland.com.pl/zlacza-ark/9443-zlacze-ark-raster-254mm-2-pin-10szt-5904422313340.html
J2 | Zasilanie_pico | TerminalBlock_Phoenix:TerminalBlock_Phoenix_MPT-0,5-2-2.54_1x02_P2.54mm_Horizontal | TAK | https://botland.com.pl/zlacza-ark/9443-zlacze-ark-raster-254mm-2-pin-10szt-5904422313340.html
J3 | GPIO_sterowanie | TerminalBlock_Phoenix:TerminalBlock_Phoenix_MPT-0,5-5-2.54_1x05_P2.54mm_Horizontal | TAK | łączysz 2+3 itp
> J4, J8 | Rmierz | Connector_PinSocket_2.00mm:PinSocket_1x01_P2.00mm_Vertical | TAK | https://www.tme.eu/pl/details/fci-76357-401/zlacza-sygnalowe-raster-2-54mm/amphenol-communications-solutions/76357-401lf/
> J5, J9 | Cmierz | Connector_PinSocket_2.00mm:PinSocket_1x01_P2.00mm_Vertical | TAK | https://www.tme.eu/pl/details/nsr-01/listwy-i-gniazda-kolkowe/ninigi/?brutto=1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
> J6, J10 | Lmierz | Connector_PinSocket_2.00mm:PinSocket_1x01_P2.00mm_Vertical | TAK | https://www.tme.eu/pl/details/zl307-1x1/listwy-i-gniazda-kolkowe/connfly/ds1002-03-1-1131/
J7 | Wyniki | TerminalBlock_Phoenix:TerminalBlock_Phoenix_MPT-0,5-3-2.54_1x03_P2.54mm_Horizontal | TAK | https://botland.com.pl/zlacza-ark/9444-zlacze-ark-raster-254mm-3-pin-10szt-5904422376260.html
J11 | Przyciski | TerminalBlock_Phoenix:TerminalBlock_Phoenix_MPT-0,5-4-2.54_1x04_P2.54mm_Horizontal | TAK | 2+2
J12 | USB_C_Receptacle_PowerOnly_6P | Connector_USB:USB_C_Receptacle_GCT_USB4125-xx-x_6P_TopMnt_Horizontal | TAK | https://www.tme.eu/pl/details/usb4105-gf-a/zlacza-usb-i-ieee1394/gct/
> Q1, Q3, Q4 | 2N7002 | Package_TO_SOT_SMD:SOT-23 | TAK | https://www.tme.eu/pl/details/2n7002-lge/tranzystory-z-kanalem-n-smd/luguang-electronic/2n7002/
> Q2, Q5 | IRLML6401 | Package_TO_SOT_SMD:SOT-23 | TAK | https://www.tme.eu/pl/details/irlml6401trpbf/tranzystory-z-kanalem-p-smd/infineon-technologies/
> R1, R5, R9, R11, R12, R_pomiar4 | 10k | Resistor_SMD:R_1206_3216Metric | TAK | https://www.tme.eu/pl/details/ar1206-10k-0.1%25/rezystory-smd/viking/ar06btcv1002/
> R2, R6 | 4.7k | Resistor_SMD:R_1206_3216Metric | TAK | https://www.tme.eu/pl/details/rc1206fr-074k7/rezystory-smd/yageo/rc1206fr-074k7l/
R3 | 470 | Resistor_SMD:R_1206_3216Metric | TAK | https://www.tme.eu/pl/details/rc1206fr-07470r/rezystory-smd/yageo/rc1206fr-07470rl/
R4 | 220 | Resistor_SMD:R_1206_3216Metric | TAK | https://www.tme.eu/pl/details/crcw1206220rfktabc/rezystory-smd/vishay/
R7 | 2.2k | Resistor_SMD:R_1206_3216Metric | TAK | https://www.tme.eu/pl/details/rc1206fr-072k2/rezystory-smd/yageo/rc1206fr-072k2l/
R8 | 10.2k | Resistor_SMD:R_1206_3216Metric | TAK | https://www.tme.eu/pl/details/ar1206-10k2-0.1%25/rezystory-smd/viking/ar06btcv1022/
R10 | 670 | Resistor_SMD:R_1206_3216Metric | TAK | https://www.tme.eu/pl/details/rc1206jr-07680r/rezystory-smd/yageo/rc1206jr-07680rl/
R13,R14 | 5.1k | Resistor_SMD:R_1206_3216Metric | TAK | https://www.tme.eu/pl/details/rc1206fr-075r1/rezystory-smd/yageo/rc1206fr-075r1l/
> R15, R16, R_pomiar1 | 1k | Resistor_SMD:R_1206_3216Metric | TAK | https://www.tme.eu/pl/details/ar1206-1k-0.1%25/rezystory-smd/viking/ar06btcv1001/
R17 | 0.4 | Resistor_SMD:R_1206_3216Metric | TAK | https://www.tme.eu/pl/details/mbr1206b5fr040s/rezystory-smd/wayon/
R18 | 1.2k | Resistor_SMD:R_1206_3216Metric | TAK | https://www.tme.eu/pl/details/rc1206fr-071k2/rezystory-smd/yageo/rc1206fr-071k2l/
R_pomiar2 | 25k | Resistor_SMD:R_1206_3216Metric | TAK | https://www.tme.eu/pl/details/ar1206-24k9-0.1%25/rezystory-smd/viking/ar06btcv2492/
R_pomiar3 | 10M | Resistor_SMD:R_1206_3216Metric | TAK | https://www.tme.eu/pl/details/rc1206fr-0710ml/rezystory-smd/yageo/
> SW1-SW4 | SW_Push | Button_Switch_THT:SW_PUSH_6mm_H8mm | TAK | mam
U1 | LM358 | Package_SO:Infineon_PG-DSO-8-24_4x5mm | TAK | https://www.tme.eu/pl/details/lm358dt/wzmacniacze-operacyjne-smd/stmicroelectronics/
U2 | LM339 | Package_SO:SO-14_3.9x8.65mm_P1.27mm | TAK | https://www.tme.eu/pl/details/lm339dt/komparatory-smd/stmicroelectronics/
U3 | TP4056-42-ESOP8 | Package_SO:SOIC-8-1EP_3.9x4.9mm_P1.27mm_EP2.41x3.3mm_ThermalVias | TAK | https://superelektronika.pl/pl/ce/284471649-tp4056-ladowarka-li-pol-li-ion-37v-1s-1a-sop8-5905427015697.html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
U4 | MCP1825S | Package_TO_SOT_SMD:SOT-223-3_TabPin2 | TAK | https://www.tme.eu/pl/details/mcp1825s-3302e_db/stabilizatory-napiecia-nieregulowane-ldo/microchip-technology/
https://allegro.pl/oferta/zestaw-wtykow-kolkowych-310-sztuk-wtyk-kolkowy-pin-meski-i-zenski-obudowy-17591629522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
https://botland.com.pl/akumulatory-li-pol-1s-37v/15627-akumulator-li-pol-akyga-2100mah-1s-37v-zlacze-jst-bec-gniazdo-83x30x5mm-5904422324339.html
https://botland.com.pl/akumulatory-li-pol-1s-37v/15604-akumulator-li-pol-akyga-510mah-1s-37v-zlacze-jst-bec-gniazdo-60x20x5mm-5904422324162.html
https://botland.com.pl/akumulatory-li-pol-1s-37v/15616-akumulator-li-pol-akyga-1050mah-1s-37v-zlacze-jst-bec-gniazdo-78x30x43mm-5904422324254.html

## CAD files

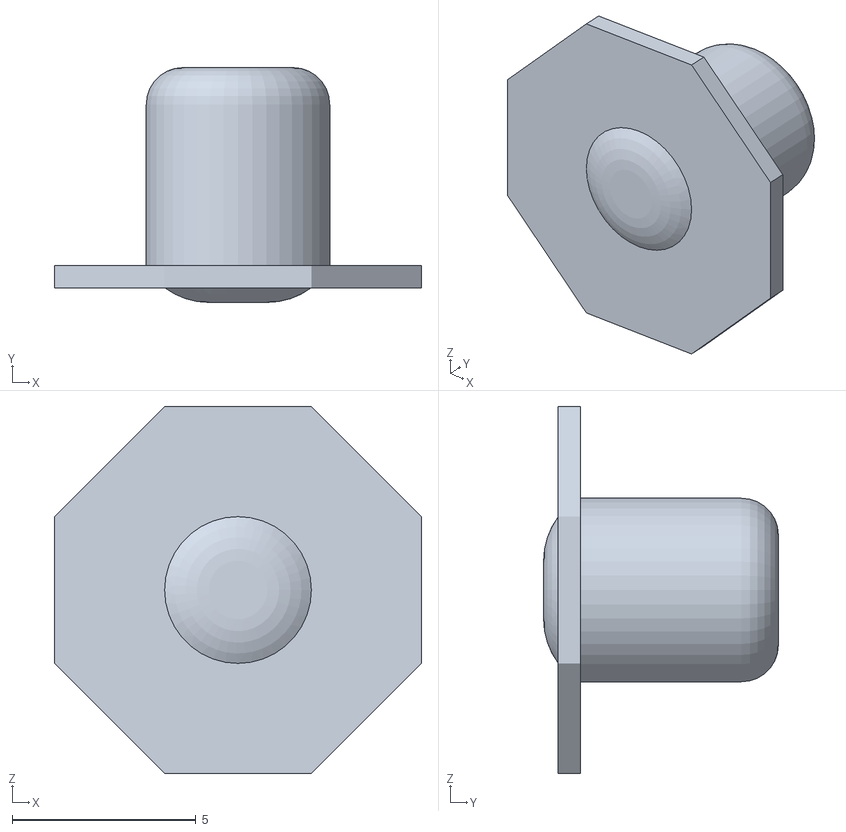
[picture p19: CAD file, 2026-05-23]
Hardware/Model/button.stl
10.0 x 6.40 x 10.0

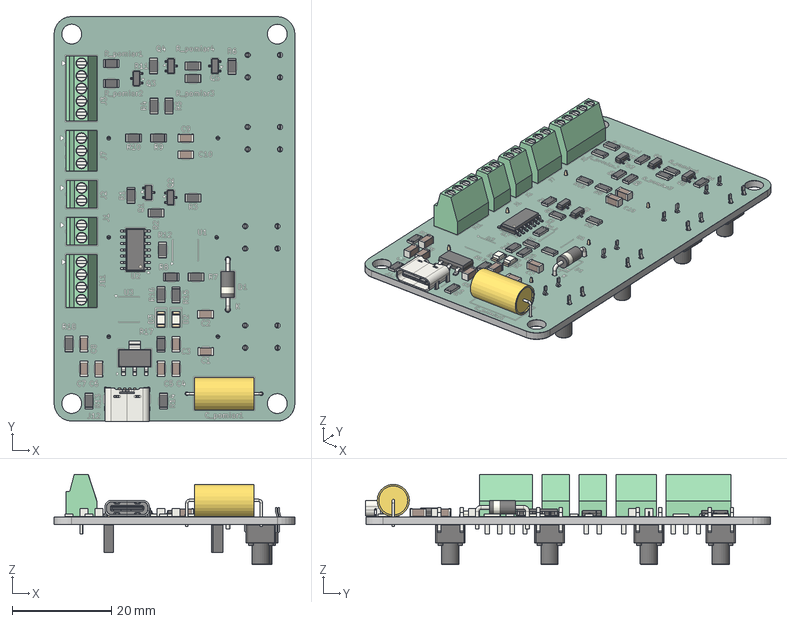
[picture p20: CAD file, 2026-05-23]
Hardware/PCB/Miernik.step
48.5 x 81.6 x 18.2 mm
SOT-23 x 5
SO-14_3.9x8.65mm_P1.27mm
R_1206_3216Metric x 22
C_1206_3216Metric x 10
LED_1206_3216Metric x 2
TerminalBlock_Phoenix_MPT-0,5-3-2.54_1x03_P2.54mm_Horizontal
D_DO-41_SOD81_P10.16mm_Horizontal
C_Axial_L12.0mm_D6.5mm_P15.00mm_Horizontal
USB_C_Receptacle_GCT_USB4125-xx-x_6P_TopMnt_Horizontal
SOT-223
TerminalBlock_Phoenix_MPT-0,5-2-2.54_1x02_P2.54mm_Horizontal x 2
TerminalBlock_Phoenix_MPT-0,5-4-2.54_1x04_P2.54mm_Horizontal
TerminalBlock_Phoenix_MPT-0,5-5-2.54_1x05_P2.54mm_Horizontal
PinSocket_1x01_P2.00mm_Vertical x 6
SW_PUSH_6mm_H8mm x 4
Miernik_silkscreen x 2
Miernik_soldermask x 2
Miernik_PCB

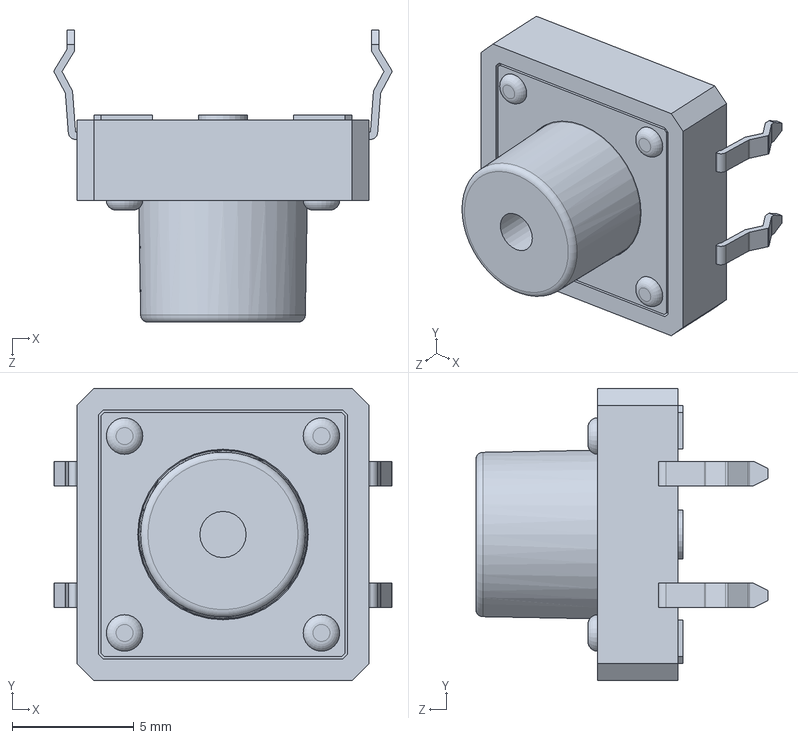
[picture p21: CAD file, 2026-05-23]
Hardware/Model/12x12x8mm.SLDPRT
13.9 x 12.0 x 12.0 mm

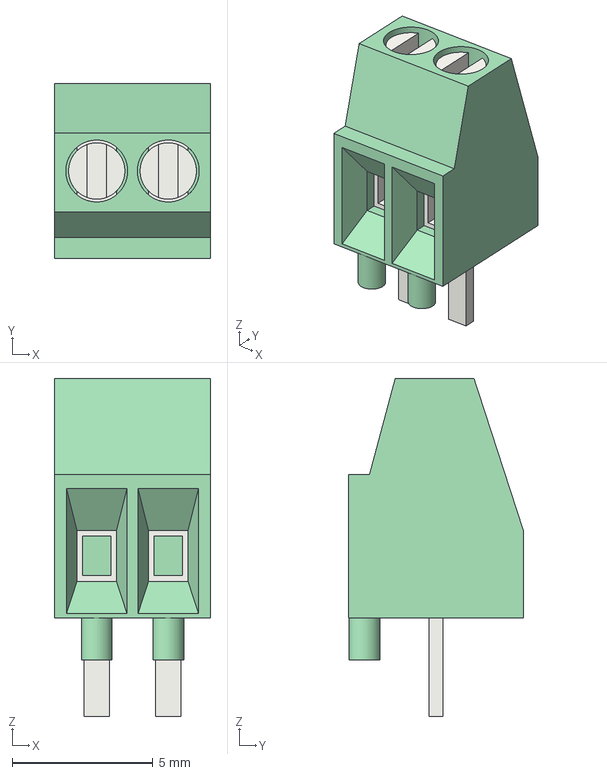
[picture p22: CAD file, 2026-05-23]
Hardware/Model/TerminalBlock_Phoenix_MPT-0,5-2-2.54_1x02_P2.54mm_Horizontal.step
5.54 x 6.20 x 12.0 mm

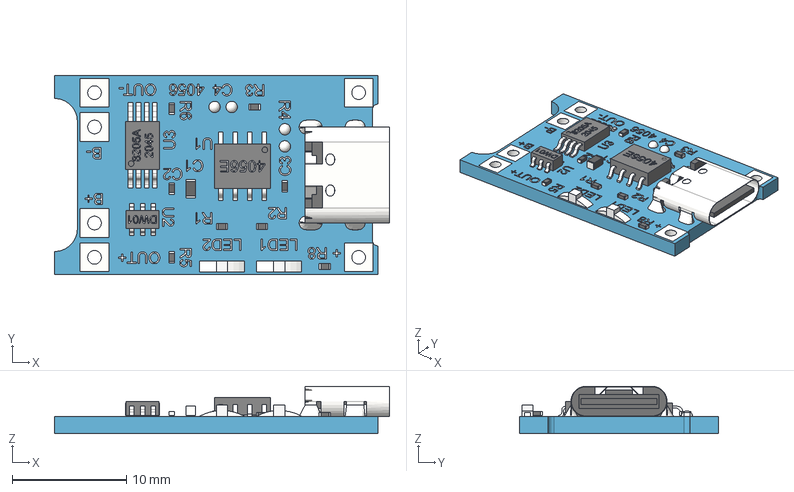
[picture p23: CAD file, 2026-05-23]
Hardware/Model/TP4056_Charging_Module_Type_C.step
29.3 x 17.4 x 4.14 mm
board
USB_Type_C_Connector
8205A_2045
DW01-P
small1005_smd_resistor x 2
small1005_smd_resistor (1)
small1005_smd_capacitor
smd_capacitor
SOP-8_4056E
solder_dot_round
solder_dot_round (1)
solder_dot_round (2)
solder_dot_round (3)
small1005_smd_capacitor (1)
LED2
LED2 (1)
small1005_smd_resistor (2)
small1005_smd_resistor (4) x 2
soldering

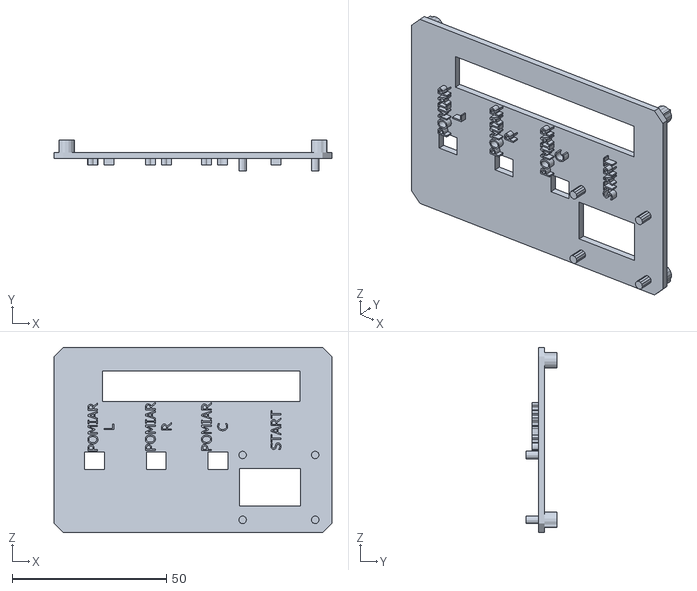
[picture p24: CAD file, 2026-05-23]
Hardware/Model/TEST.stl
90.0 x 10.0 x 60.0

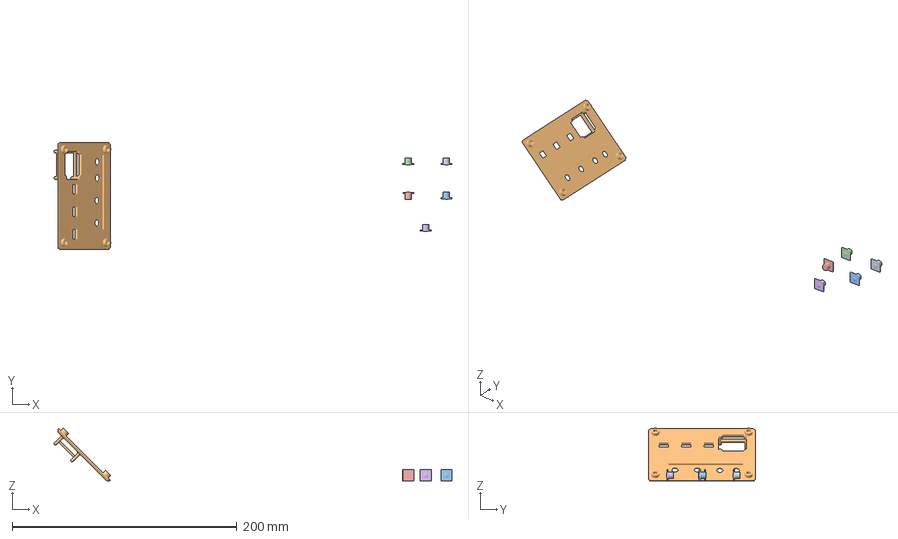
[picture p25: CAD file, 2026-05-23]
Hardware/Model/gora.3mf
354.5 x 95.0 x 47.0 mm
button.stl x 5
gora.stl

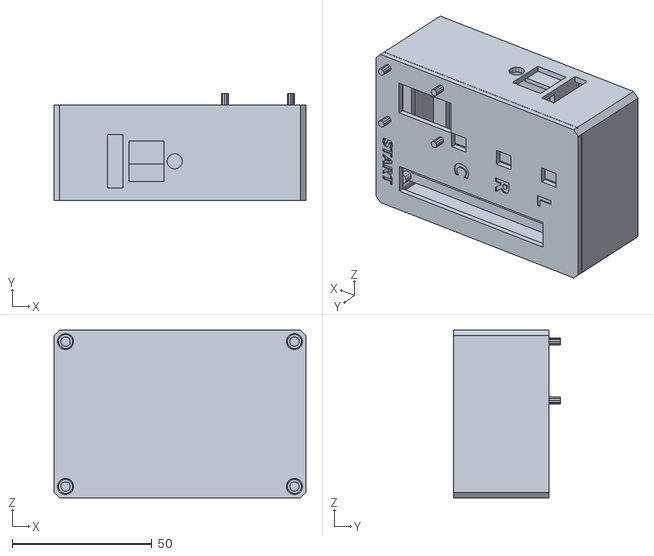
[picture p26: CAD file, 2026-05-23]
Hardware/Model/Zespół1.stl
90.0 x 38.1 x 60.0

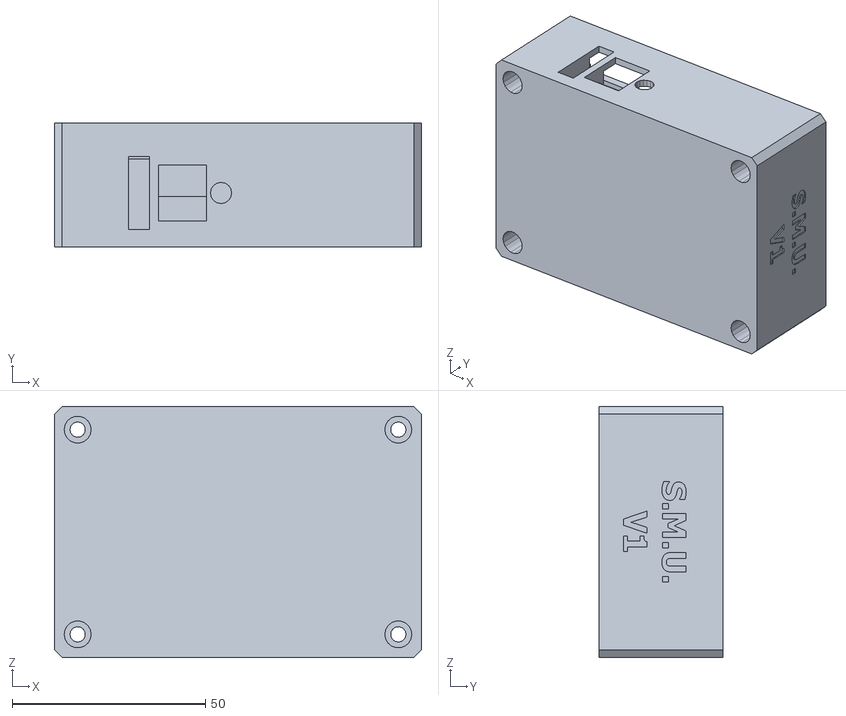
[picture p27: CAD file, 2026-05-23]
Hardware/Model/spod.stl
95.0 x 32.0 x 65.0

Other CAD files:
Hardware/Model/12x12x8mm/12x12x8mm/12x12x8mm.ipt
Hardware/Model/5mm_LED_Red.ipt
Hardware/Model/OldVersions/Zespół1.0006.iam
Hardware/Model/OldVersions/button.0003.ipt
Hardware/Model/OldVersions/gora.0006.ipt
Hardware/Model/OldVersions/spod.0004.ipt
Hardware/Model/TP4056_Charging_Module_Type_C/TP4056_Charging_Module_Type_C/TP4056_Charging_Module_Type_C.ipt
Hardware/Model/TerminalBlock_Phoenix_MPT-0,5-2-2.54_1x02_P2.54mm_Horizontal/TerminalBlock_Phoenix_MPT-0,5-2-2.54_1x02_P2.54mm_Horizontal/TerminalBlock_Phoenix_MPT-0,5-2-2.54_1x02_.ipt
Hardware/Model/Zespół1.iam
Hardware/Model/atrapa_ogniwa.ipt
Hardware/Model/button.ipt
Hardware/Model/gora.ipt
Hardware/Model/gora.stl
Hardware/Model/spod.ipt

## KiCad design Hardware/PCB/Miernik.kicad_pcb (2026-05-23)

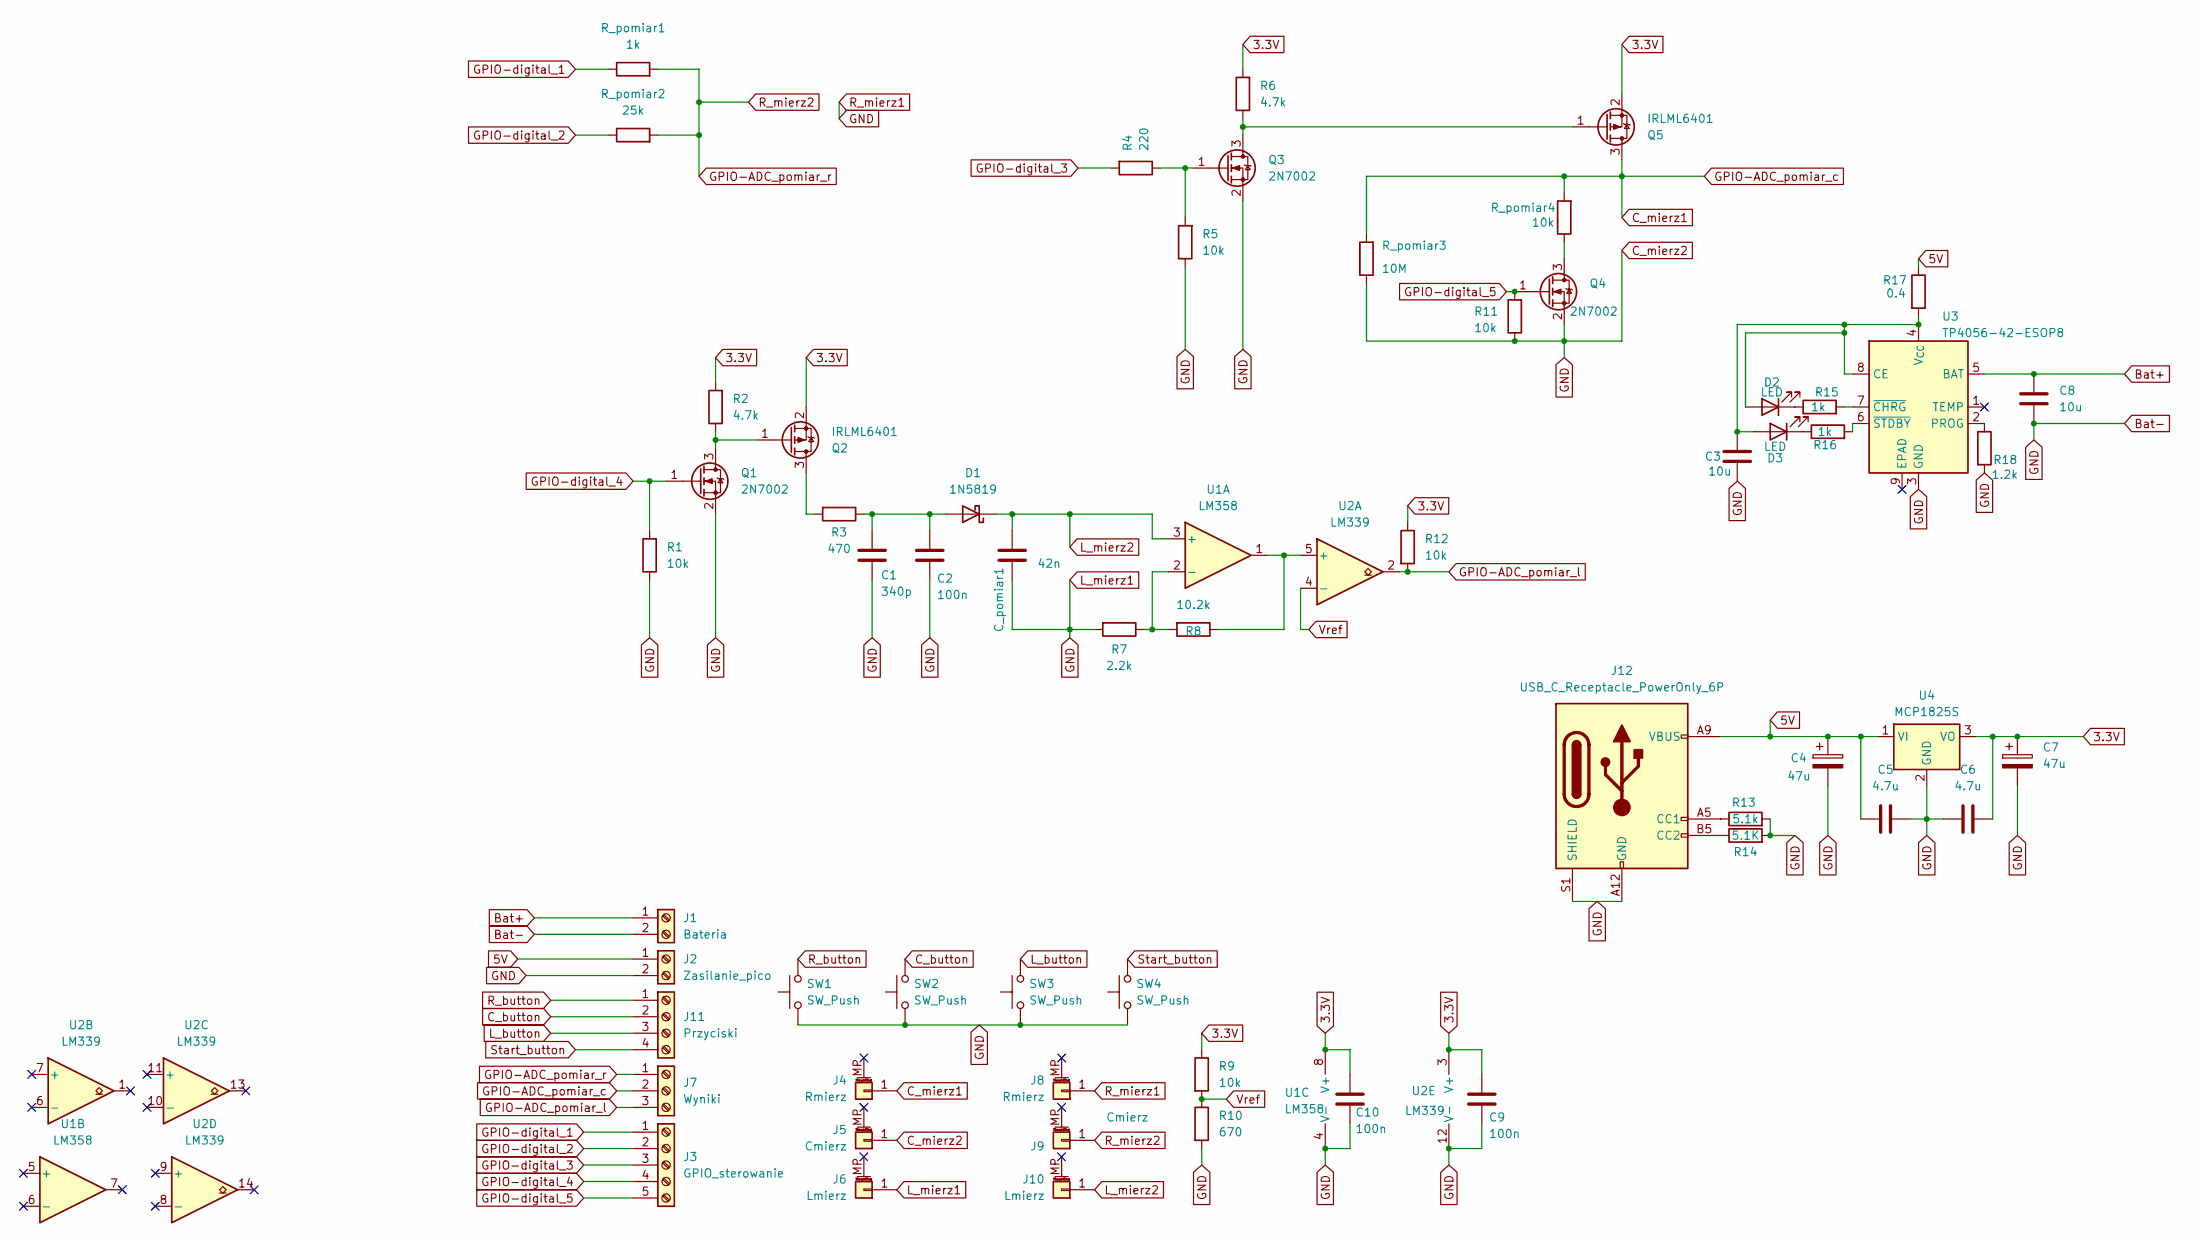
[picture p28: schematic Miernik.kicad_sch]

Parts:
C1: 340p; C_1206_3216Metric
C2, C9, C10: 100n; C_1206_3216Metric
C3, C8: 10u; C_1206_3216Metric
C4, C7: 47u; C_1206_3216Metric
C5, C6: 4.7u; C_1206_3216Metric
C_pomiar1: 42n; C_Axial_L12.0mm_D6.5mm_P15.00mm_Horizontal
D1: 1N5819; D_DO-41_SOD81_P10.16mm_Horizontal
D2, D3: LED; LED_1206_3216Metric
J1: Bateria; TerminalBlock_Phoenix_MPT-0,5-2-2.54_1x02_P2.54mm_Horizontal
J2: Zasilanie_pico; TerminalBlock_Phoenix_MPT-0,5-2-2.54_1x02_P2.54mm_Horizontal
J3: GPIO_sterowanie; TerminalBlock_Phoenix_MPT-0,5-5-2.54_1x05_P2.54mm_Horizontal
J4, J8: Rmierz; PinSocket_1x01_P2.00mm_Vertical
J5, J9: Cmierz; PinSocket_1x01_P2.00mm_Vertical
J6, J10: Lmierz; PinSocket_1x01_P2.00mm_Vertical
J7: Wyniki; TerminalBlock_Phoenix_MPT-0,5-3-2.54_1x03_P2.54mm_Horizontal
J11: Przyciski; TerminalBlock_Phoenix_MPT-0,5-4-2.54_1x04_P2.54mm_Horizontal
J12: USB_C_Receptacle_PowerOnly_6P; USB_C_Receptacle_GCT_USB4125-xx-x_6P_TopMnt_Horizontal
Q1, Q3, Q4: 2N7002; SOT-23
Q2, Q5: IRLML6401; SOT-23
R1, R5, R9, R11, R12: 10k; R_1206_3216Metric
R2, R6: 4.7k; R_1206_3216Metric
R3: 470; R_1206_3216Metric
R4: 220; R_1206_3216Metric
R7: 2.2k; R_1206_3216Metric
R8: 10.2k; R_1206_3216Metric
R10: 670; R_1206_3216Metric
R13: 5.1k; R_1206_3216Metric
R14: 5.1K; R_1206_3216Metric
R15, R16: 1k; R_1206_3216Metric
R17: 0.4; R_1206_3216Metric
R18: 1.2k; R_1206_3216Metric
R_pomiar1: 1k; R_1206_3216Metric
R_pomiar2: 25k; R_1206_3216Metric
R_pomiar3: 10M; R_1206_3216Metric
R_pomiar4: 10k; R_1206_3216Metric
SW1, SW2, SW3, SW4: SW_Push; SW_PUSH_6mm_H8mm
U1: LM358; Infineon_PG-DSO-8-24_4x5mm
U2: LM339; SO-14_3.9x8.65mm_P1.27mm
U3: TP4056-42-ESOP8; SOIC-8-1EP_3.9x4.9mm_P1.27mm_EP2.41x3.3mm_ThermalVias
U4: MCP1825S; SOT-223-3_TabPin2

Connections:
3.3V: C6.2, C7.1, C9.1, C10.1, Q2.2 (S), Q5.2 (S), R2.2, R6.2, R9.1, R12.1, U1.8 (V+), U2.3 (V+), U4.3 (VO)
5V: C4.1, C5.1, J2.1, J12.A9 (VBUS), J12.B9 (VBUS), R17.1, U4.1 (VI)
Bat+: C8.2, J1.1, U3.5 (BAT)
C_button: J11.2, SW2.2
C_mierz1: J4.1, J7.2, Q5.3 (D), R_pomiar3.2, R_pomiar4.2
GND: C1.2, C2.2, C3.1, C4.2, C5.2, C6.1, C7.2, C8.1, C9.2, C10.2, C_pomiar1.2, J1.2, J2.2, J5.1, J6.1, J8.1, J12.A12 (GND), J12.B12 (GND), J12.S1 (SHIELD), Q1.2 (S), Q3.2 (S), Q4.2 (S), R1.1, R5.1, R7.2, R10.2, R11.1, R13.2, R14.2, R18.2, R_pomiar3.1, SW1.1, SW2.1, SW3.1, SW4.1, U1.4 (V-), U2.12 (V-), U3.3 (GND), U4.2 (GND)
GPIO-ADC_pomiar_l: J7.3, R12.2, U2.2
GPIO-ADC_pomiar_r: J7.1, J9.1, R_pomiar1.2, R_pomiar2.2
GPIO-digital_1: J3.1, R_pomiar1.1
GPIO-digital_2: J3.2, R_pomiar2.1
GPIO-digital_3: J3.3, R4.2
GPIO-digital_4: J3.4, Q1.1 (G), R1.2
GPIO-digital_5: J3.5, Q4.1 (G), R11.2
L_button: J11.3, SW3.2
L_mierz2: C_pomiar1.1, D1.1 (K), J10.1, U1.3 (+)
unnamed: C1.1, C2.1, D1.2 (A), R3.1
unnamed: C3.2, D2.2 (A), D3.2 (A), R17.2, U3.4 (V_{CC}), U3.8 (CE)
unnamed: D2.1 (K), R15.1
unnamed: D3.1 (K), R16.1
unnamed: J12.A5 (CC1), R13.1
unnamed: J12.B5 (CC2), R14.1
unnamed: Q1.3 (D), Q2.1 (G), R2.1
unnamed: Q2.3 (D), R3.2
unnamed: Q3.3 (D), Q5.1 (G), R6.1
unnamed: Q3.1 (G), R4.1, R5.2
unnamed: Q4.3 (D), R_pomiar4.1
unnamed: R7.1, R8.2, U1.2 (-)
unnamed: R8.1, U1.1, U2.5 (+)
unnamed: R18.1, U3.2 (PROG)
unnamed: R15.2, U3.7 (~CHRG)
unnamed: R16.2, U3.6 (~STDBY)
R_button: J11.1, SW1.2
Start_button: J11.4, SW4.2
Vref: R9.2, R10.1, U2.4 (-)

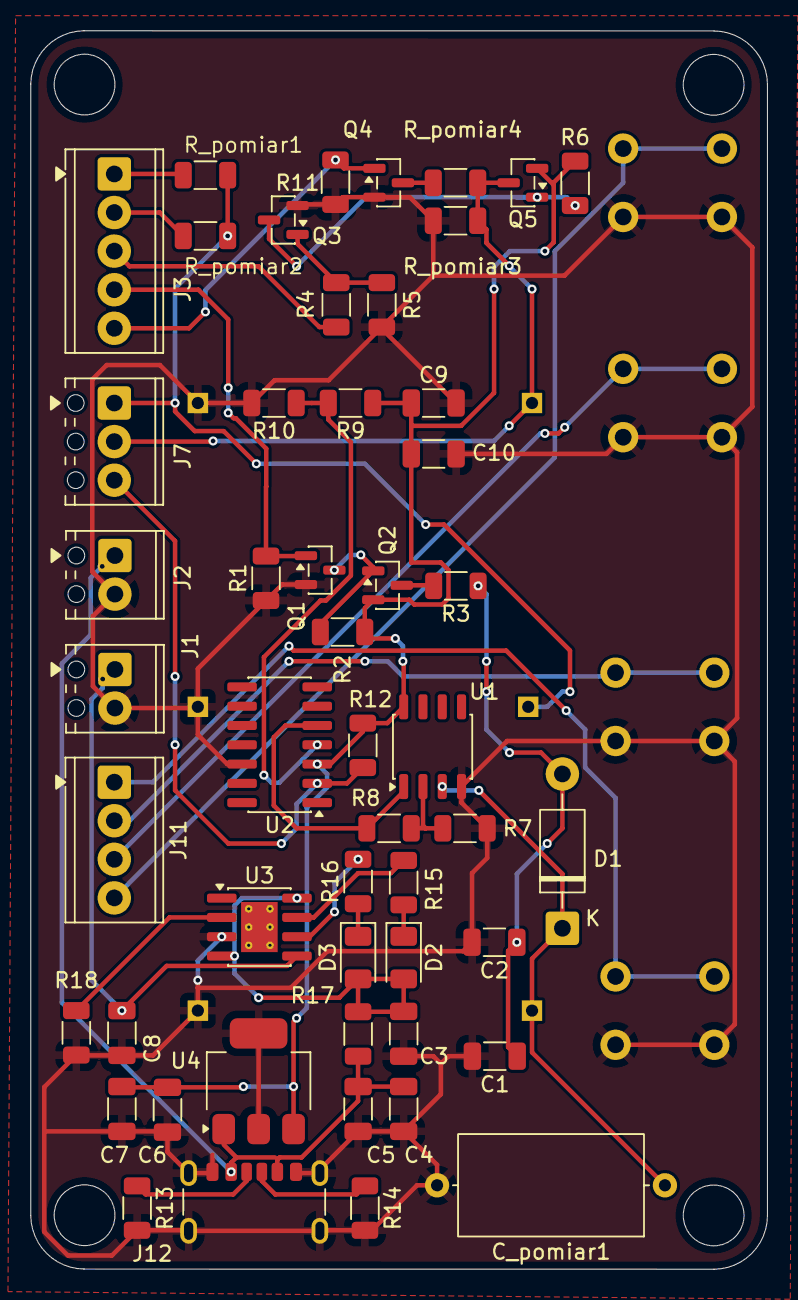
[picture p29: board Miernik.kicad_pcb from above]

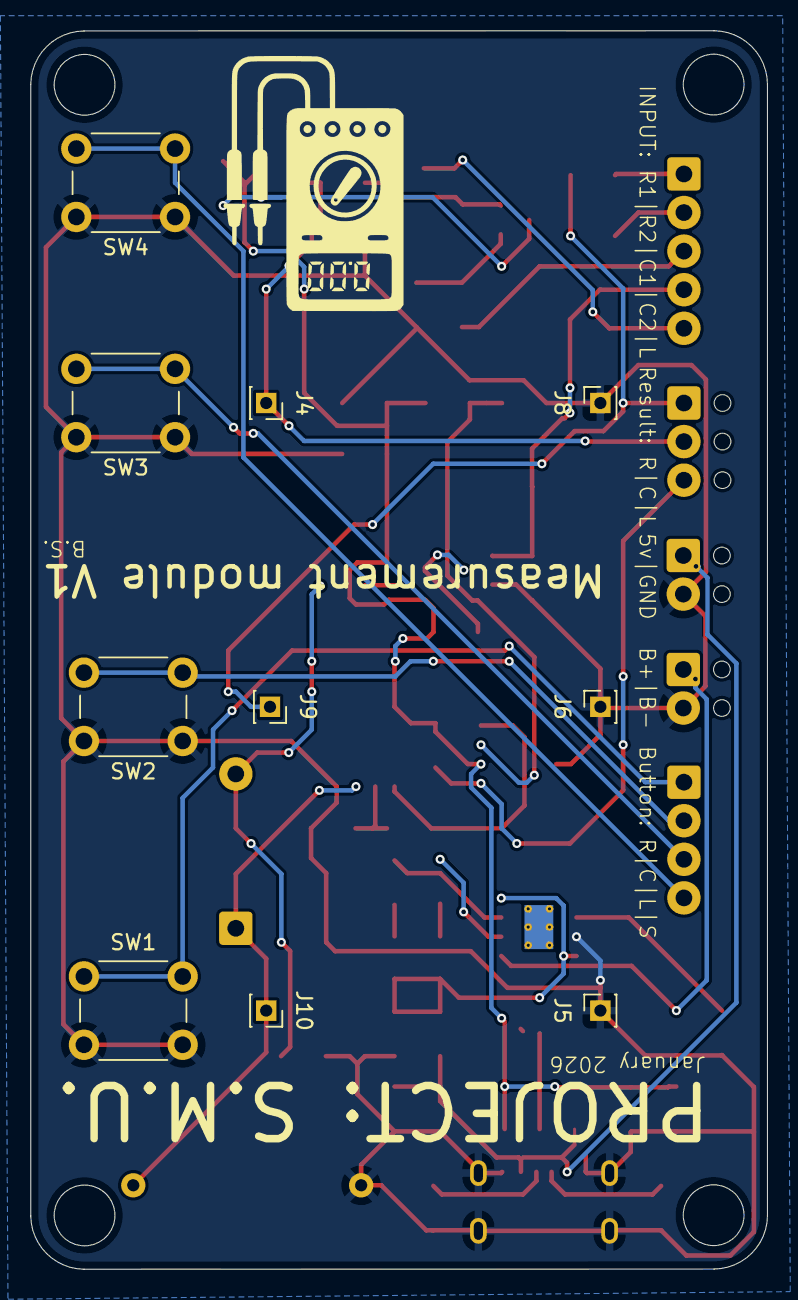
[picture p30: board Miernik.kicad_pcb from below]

Board: 2 copper layers, 48.5 x 81.5 mm, 61 parts (10 on the bottom side), 34 nets.

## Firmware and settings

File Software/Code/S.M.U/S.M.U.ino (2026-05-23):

#include <Wire.h>
#include <Adafruit_GFX.h>
#include <Adafruit_SSD1306.h>
#include <math.h>
#include <cstdio>

// ===== OLED =====
#define SCREEN_WIDTH 128
#define SCREEN_HEIGHT 32
#define OLED_RESET     -1
#define SCREEN_ADDRESS 0x3C
Adafruit_SSD1306 display(SCREEN_WIDTH, SCREEN_HEIGHT, &Wire, OLED_RESET);

// ===== Stałe / kalibracje =====
unsigned long time_start, time_koniec;
float C_offset = 755.5f * 1e-12f;
float L_offset = 100e-6;

float v_ref = 3.3f;
float resoulution = 4095.0f;

// R 
float R_wzorcowe_1  = 992.4f;     // ~1k
float R_wzorcowe_2  = 24580.0f;   // ~25k

// C
float R_C_10M = 10.0e6f;   // <-- najlepiej podmień na zmierzone
float R_C_10K = 10.0e3f;   // <-- najlepiej podmień na zmierzone

// L
float C_wzorcowe = 0.000000042f; // 42 nF

// ===== Piny =====
// wyjścia
int R_pomiar_1k   = 11;
int R_pomiar_25k  = 12;

int C_pomiar_10M  = 13;  // CHARGE
int C_pomiar_10k  = 15;  // FAST DISCHARGE

int L_pomiar      = 14;
int Led_power_on  = 1;

int wynik_pomiaru_R = A1;
int wynik_pomiaru_C = A0;
int wynik_pomiaru_L = 2;  

int R_button      = 17; 
int C_button      = 16;
int L_button      = 19;
int start         = 18;

// ========================= OLED helpers =========================
void Clearline(uint8_t linia, uint8_t size) {
  uint8_t y = linia * 8;
  uint8_t h = 8 * size;
  if (y >= SCREEN_HEIGHT) return;
  display.fillRect(0, y, SCREEN_WIDTH, h, SSD1306_BLACK);
}

void slowodruk(const char* tekst, uint8_t linia, int Size) {
  Clearline(linia, Size);
  display.setTextSize(Size);
  display.setTextColor(SSD1306_WHITE);
  uint8_t y = linia * 8;
  if (y >= SCREEN_HEIGHT) return;
  display.setCursor(0, y);
  display.print(tekst);
  display.display();
}

// ========================= Format helpers =========================
const char* drukRes(float R){
  static char buf[24];
  if (isnan(R) || R <= 0.0f) { snprintf(buf, sizeof(buf), "R=ERR"); return buf; }

  float v = R;
  const char* u = "ohm";
  if (v >= 1e9f)      { v /= 1e9f; u = "Gohm"; }
  else if (v >= 1e6f) { v /= 1e6f; u = "Mohm"; }
  else if (v >= 1e3f) { v /= 1e3f; u = "kohm"; }

  snprintf(buf, sizeof(buf), "%.2f%s", v, u);
  return buf;
}

const char* drukCap(float F){
  static char buf[24];
  if (isnan(F) || F <= 0.0f) { snprintf(buf, sizeof(buf), "C=ERR"); return buf; }

  float v = F; const char* u = "F";
  if (v >= 1e-3f)      { v *= 1e3f;  u = "mF"; }
  else if (v >= 1e-6f) { v *= 1e6f;  u = "uF"; }
  else if (v >= 1e-9f) { v *= 1e9f;  u = "nF"; }
  else                 { v *= 1e12f; u = "pF"; }

  snprintf(buf, sizeof(buf), "%.2f %s", v, u);
  return buf;
}

const char* drukFreq(float f){
  static char buf[24];
  if (!isfinite(f) || f <= 0.0f) { snprintf(buf, sizeof(buf), "f=ERR"); return buf; }

  float v = f; const char* u = "Hz";
  if (v >= 1e6f)      { v /= 1e6f; u = "MHz"; }
  else if (v >= 1e3f) { v /= 1e3f; u = "kHz"; }

  snprintf(buf, sizeof(buf), "f=%.2f %s", v, u);
  return buf;
}

const char* drukInd(float L){
  static char buf[24];
  if (!isfinite(L) || L <= 0.0f) { snprintf(buf, sizeof(buf), "L=ERR"); return buf; }

  float v = L; const char* u = "H";
  if (v < 1e-3f)      { v *= 1e6f; u = "uH"; }
  else if (v < 1.0f)  { v *= 1e3f; u = "mH"; }

  snprintf(buf, sizeof(buf), "%.2f %s", v, u);
  return buf;
}

// ========================= Pomiar R =========================
static float Pomiar_R(){
  pinMode(R_pomiar_1k, OUTPUT);  digitalWrite(R_pomiar_1k, HIGH);
  pinMode(R_pomiar_25k, INPUT);
  delay(200);
  float value_1 = analogRead(wynik_pomiaru_R);

  pinMode(R_pomiar_25k, OUTPUT); digitalWrite(R_pomiar_25k, HIGH);
  pinMode(R_pomiar_1k, INPUT);
  delay(200);
  float value_2 = analogRead(wynik_pomiaru_R);

  digitalWrite(R_pomiar_25k, LOW);
  delay(50);

  float srodek = resoulution / 2.0f;
  float A_1 = value_1 - srodek;
  float A_2 = value_2 - srodek;

  float R_ref, v_adc;
  if (fabsf(A_2) > fabsf(A_1)) { R_ref = R_wzorcowe_1; v_adc = value_1; }
  else                         { R_ref = R_wzorcowe_2; v_adc = value_2; }

  float v_meas = v_adc * v_ref / resoulution;
  float v_refdrop = v_ref - v_meas;
  float I = v_refdrop / R_ref;
  if (I <= 0.0f) return NAN;

  return v_meas / I;
}

// ========================= Pomiar C  =========================
static inline void C_chargeOn()        { digitalWrite(C_pomiar_10M, HIGH); } // Q5 ON
static inline void C_chargeOff()       { digitalWrite(C_pomiar_10M, LOW);  } // Q5 OFF
static inline void C_fastDisOn()       { digitalWrite(C_pomiar_10k, HIGH); } // Q4 ON -> 10k do GND
static inline void C_fastDisOff()      { digitalWrite(C_pomiar_10k, LOW);  } // Q4 OFF -> zostaje tylko 10M

static void C_fullDischarge(uint16_t ms=200) {
  // szybko rozładuj żeby start zawsze był powtarzalny
  C_chargeOff();
  C_fastDisOn();
  delay(ms);
  C_fastDisOff();
}

// ładowanie do ~3.3V (ale z limitem czasu, żeby nie wisieć wiecznie)
static float C_chargeAndReadV0() {
  C_fastDisOff();   // podczas ładowania fast-discharge wyłączony
  C_chargeOn();
  uint32_t t0 = millis();

  float v = 0;
  while (true) {
    (void)analogRead(wynik_pomiaru_C);
    v = (float)analogRead(wynik_pomiaru_C);

    if (v > 0.98f * resoulution) break;       
    if ((millis() - t0) > 400) break;        
  }

  C_chargeOff();
  delayMicroseconds(200);

  (void)analogRead(wynik_pomiaru_C);
  v = (float)analogRead(wynik_pomiaru_C);
  return v;
}

static float C_measureDischarge_us(bool fast, uint32_t timeout_us) {
  float v0 = C_chargeAndReadV0();
  if (v0 < 0.2f * resoulution) return NAN;

  float thr = v0 * 0.367879f;

  // start rozładowania
  if (fast) C_fastDisOn();
  else      C_fastDisOff(); // zostaje 10M

  uint32_t t_start = micros();
  while (true) {
    float v = (float)analogRead(wynik_pomiaru_C);
    if (v <= thr) break;
    if ((micros() - t_start) > timeout_us) {
      if (fast) C_fastDisOff();
      return NAN;
    }
  }
  uint32_t t_end = micros();

  if (fast) C_fastDisOff();
  return (float)(t_end - t_start);
}

static float C_req(bool fast) {
  if (!fast) return R_C_10M;
  float denom = (1.0f / R_C_10K) + (1.0f / R_C_10M);
  if (denom <= 0.0f) return NAN;
  return 1.0f / denom;
}

static float Pomiar_C() {
  // autorange:
  // 1) próbuj slow (10M) z krótkim timeout
  // 2) jak za długo -> fast (10k) z długim timeout (pod duże elektrolity)
  // + uśrednianie 3 pomiarów w wybranym trybie

  // najpierw wymuś znany start
  C_fullDischarge(120);

  bool fast = false;
  float t_us = C_measureDischarge_us(false, 1200000UL); // 1.2s

  if (!isfinite(t_us)) {
    fast = true;
    C_fullDischarge(120);
    t_us = C_measureDischarge_us(true, 12000000UL);     // 12s (ok. do ~1mF przy 10k)
  }
  if (!isfinite(t_us)) return NAN;

  // uśrednij 3 pomiary
  float sum = t_us;
  int cnt = 1;
  for (int i = 0; i < 2; i++) {
    C_fullDischarge(80);
    float ti = C_measureDischarge_us(fast, fast ? 12000000UL : 1200000UL);
    if (isfinite(ti)) { sum += ti; cnt++; }
  }
  float avg_us = sum / (float)cnt;

  float R = C_req(fast);
  if (!isfinite(R) || R <= 0.0f) return NAN;

  float C = (avg_us * 1e-6f) / R; // t = R*C
  C -= C_offset;
  if (C < 0.0f) C = 0.0f;

  // rozładuj na koniec
  C_fullDischarge(120);
  return C;
}

// ========================= Pomiar L (burst + LM339) =========================
const uint16_t MIN_EDGES    = 5;
const uint32_t STOP_GAP_US  = 250;
const uint32_t MAX_WAIT_US  = 5000;
const uint16_t PULSE_US     = 10; 

volatile uint32_t t_first = 0;
volatile uint32_t t_last  = 0;
volatile uint32_t t_edge  = 0;
volatile uint16_t edges   = 0;

void onEdgeISR() {
  uint32_t t = micros();
  if (edges == 0) t_first = t;
  t_last = t;
  t_edge = t;
  edges++;
}

float measureFreqBurstHz() {
  noInterrupts();
  edges = 0;
  t_first = t_last = t_edge = 0;
  interrupts();

  attachInterrupt(digitalPinToInterrupt(wynik_pomiaru_L), onEdgeISR, FALLING);

  // wzbudzenie
  digitalWrite(L_pomiar, HIGH);
  delayMicroseconds(PULSE_US);
  digitalWrite(L_pomiar, LOW);

  uint32_t t0 = micros();
  while (true) {
    uint32_t now = micros();

    uint16_t e;
    uint32_t lastE;
    noInterrupts();
    e = edges;
    lastE = t_edge;
    interrupts();

    if (e >= MIN_EDGES && (now - lastE) > STOP_GAP_US) break;
    if ((now - t0) > MAX_WAIT_US) break;
  }

  detachInterrupt(digitalPinToInterrupt(wynik_pomiaru_L));

  uint16_t e;
  uint32_t a, b;
  noInterrupts();
  e = edges;
  a = t_first;
  b = t_last;
  interrupts();

  if (e < 2 || b <= a) return NAN;

  float dt_us = (float)(b - a);
  float f = (float)(e - 1) * 1e6f / dt_us;
  return f;
}

float Pomiar_L() {
  // proste uśrednianie 3 burstów (stabilniejsze)
  float fsum = 0; int n = 0;
  for (int i = 0; i < 3; i++) {
    float f = measureFreqBurstHz();
    if (isfinite(f) && f > 0.0f) { fsum += f; n++; }
    delay(30);
  }
  if (n == 0) return NAN;

  float f = fsum / (float)n;
  float w = 6.28318530718f * f;
  return 1.0f / (w * w * C_wzorcowe);
}

// ========================= UI: wybór trybu + START =========================
enum Mode { MODE_NONE, MODE_R, MODE_C, MODE_L };
Mode aktualny = MODE_NONE;

bool lastR = true, lastC = true, lastL = true, lastS = true;
uint32_t dbR=0, dbC=0, dbL=0, dbS=0;

bool pressedEdge(int pin, bool &lastState, uint32_t &lastDbMs) {
  bool now = digitalRead(pin); // pullup: true=puszczony, false=wcisniety
  bool ev = false;
  if (lastState == true && now == false) {
    uint32_t t = millis();
    if (t - lastDbMs > 160) { ev = true; lastDbMs = t; }
  }
  lastState = now;
  return ev;
}

void pokazTryb() {
  Clearline(1, 2);

  if (aktualny == MODE_NONE) {
    slowodruk("Wybierz pomiar:", 0, 1);
    slowodruk("R / C / L  + Start", 1, 1);
    return;
  }

  if (aktualny == MODE_R) slowodruk("Aktualny pomiar: R", 0, 1);
  if (aktualny == MODE_C) slowodruk("Aktualny pomiar: C", 0, 1);
  if (aktualny == MODE_L) slowodruk("Aktualny pomiar: L", 0, 1);

  slowodruk("Wcisnij Start", 1, 1);

  Clearline(2, 2);
  Clearline(3, 2);
}

void setup() {
  Serial.begin(9600);
  analogReadResolution(12);
  delay(200);

  pinMode(R_pomiar_1k, OUTPUT);    digitalWrite(R_pomiar_1k, LOW);
  pinMode(R_pomiar_25k, OUTPUT);   digitalWrite(R_pomiar_25k, LOW);

  pinMode(C_pomiar_10M, OUTPUT);   digitalWrite(C_pomiar_10M, LOW); // CHARGE OFF
  pinMode(C_pomiar_10k, OUTPUT);   digitalWrite(C_pomiar_10k, LOW); // FAST OFF

  pinMode(L_pomiar, OUTPUT);       digitalWrite(L_pomiar, LOW);

  pinMode(wynik_pomiaru_R, INPUT);
  pinMode(wynik_pomiaru_C, INPUT);
  pinMode(wynik_pomiaru_L, INPUT);
  pinMode(R_button, INPUT_PULLUP);
  pinMode(C_button, INPUT_PULLUP);
  pinMode(L_button, INPUT_PULLUP);
  pinMode(start,    INPUT_PULLUP);

  pinMode(Led_power_on, OUTPUT);
  digitalWrite(Led_power_on, HIGH);

  if (!display.begin(SSD1306_SWITCHCAPVCC, SCREEN_ADDRESS)) {
    while (1) { delay(100); }
  }
  display.clearDisplay();
  display.display();

  pokazTryb();
}

void loop() {
  if (pressedEdge(R_button, lastR, dbR)) { aktualny = MODE_R; pokazTryb(); }
  if (pressedEdge(C_button, lastC, dbC)) { aktualny = MODE_C; pokazTryb(); }
  if (pressedEdge(L_button, lastL, dbL)) { aktualny = MODE_L; pokazTryb(); }

  if (pressedEdge(start, lastS, dbS)) {
    if (aktualny == MODE_NONE) { pokazTryb(); return; }

    slowodruk("Mierze...", 0, 1);
    Clearline(1, 2);
    Clearline(2, 2);
    Clearline(3, 2);

    if (aktualny == MODE_R) {
      float r = Pomiar_R();
      slowodruk(drukRes(r), 1, 2);
      Serial.print(""); Serial.println(r, 6);
    }
    else if (aktualny == MODE_C) {
      float c = Pomiar_C();
      slowodruk(drukCap(c), 1, 2);
      Serial.print(""); Serial.println(c, 12);
    }
    else if (aktualny == MODE_L) {
      float f = measureFreqBurstHz();
      float L = NAN;
      if (isfinite(f) && f > 0.0f) {
        float w = 6.28318530718f * f;
        L = 1.0f / (w * w * C_wzorcowe);
      }

      slowodruk(drukFreq(f), 0, 1);
      slowodruk(drukInd(L-L_offset),  1, 2);

      Serial.print("edges="); Serial.print((int)edges);
      Serial.print("  f=");   Serial.print(f, 2); Serial.print(" Hz");
      Serial.print("  ");   Serial.print(L, 12); Serial.println(" H");
    }
  }
}

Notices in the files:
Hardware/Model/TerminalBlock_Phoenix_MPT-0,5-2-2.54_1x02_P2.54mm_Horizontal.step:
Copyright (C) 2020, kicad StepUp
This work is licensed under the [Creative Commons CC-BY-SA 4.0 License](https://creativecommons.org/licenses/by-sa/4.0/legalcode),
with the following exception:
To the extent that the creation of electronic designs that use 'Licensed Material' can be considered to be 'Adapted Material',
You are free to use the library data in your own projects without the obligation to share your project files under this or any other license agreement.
